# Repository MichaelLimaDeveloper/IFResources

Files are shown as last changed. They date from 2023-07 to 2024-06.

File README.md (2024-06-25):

# IFResources
Controle e Monitoramento de Temperatura e Recursos Hídricos.

## Objetivo
Este repositório foi criado para a publicação dos códigos, documentos e outros arquivos utilizados para a apresentação na disciplina de Projeto Final lecionada por Prof. Dr. Alexandre Domingues Gonçalvez e para a obtenção do grau de Técnico em Informática.

## Resumo
Os arquivos aqui publicados e os temas propostos no documento falam sobre o desenvolvimento de um Web-Site que faz conexão com um micro-controlador do modelo LORA-32 por meio de uma instância Docker hospedada no serviço AWS. Nesse Web-Site são dadas informações como a temperatura e umidade do ambiente dos sensores, a porcentagem do volume de água em um recipiente cujo foi instalado o sensor LC1BD04 e também possibilita o envio de comandos para o infravermelho instalado no dispositivo.

## Créditos
[Gabriel Sales Rodrigues](https://github.com/gaabpng) [Michael Monteiro de Lima](https://github.com/MichaelLimaDeveloper) [Luiz Felipe Silva Oliveira](https://github.com/luizsoliveira)

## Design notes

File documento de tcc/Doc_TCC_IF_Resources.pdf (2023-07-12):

Instituto Federal de Educação, Ciência e

Tecnologia do Rio de Janeiro

### Campus Niterói

Técnico em Informática Integrado ao Ensino

Médio

Gabriel Sales Rodrigues

Michael Monteiro de Lima

Miryam Estábila Nogueira de Souza

# IF Resources:

# Controle e Monitoramento

# de Temperatura e Recursos

# Hídricos

Niterói

2023.1

Gabriel Sales Rodrigues

Michael Monteiro de Lima

Miryam Estábila Nogueira de Souza

## IF RESOURCES:

## CONTROLE E MONITORAMENTO DE TEMPERATURA E RECURSOS HÍDRICOS

Trabalho de Conclusão de Curso submetido ao corpo docente do Instituto Federal de Educação, Ciência e Tecnologia do Rio de Janeiro como requisito parcial para a obtenção do grau de Técnico em Informática.

Orientador: Prof. DSc. Luiz Felipe da Silva Oliveira

Coorientador: Prof. DSc. Alexandre Domingues Gonçalves

Niterói
2023.1

Gabriel Sales Rodrigues

Michael Monteiro de Lima

Miryam Estábila Nogueira de Souza

## IF RESOURCES: CONTROLE E MONITORAMENTO DE TEMPERATURA E RECURSOS HÍDRICOS

Trabalho de Conclusão de Curso submetido ao corpo docente do Instituto Federal de Educação, Ciência e Tecnologia do Rio de Janeiro como requisito parcial para a obtenção do grau de Técnico em Informática.

BANCA EXAMINADORA

Prof. DSc. Luiz Felipe da Silva Oliveira Orientador/IFRJ

Prof. DSc. Alexandre Domingues Gonçalves
Co-Orientador/IFRJ

Dedicamos este trabalho primeiramente a Deus, que nos concedeu a força e a sabedoria necessárias para vencer todos os obstáculos e chegar até aqui. Dedicamos também aos nossos amigos, pelos momentos de descontração que ajudaram a aliviar o estresse e a tensão durante essa caminhada acadêmica. Dedicamos esse trabalho também um ao outro, por não nos abandonarmos durante os 6 longos períodos letivos cursados.

# AGRADECIMENTOS

Ao Instituto Federal de Educação, Ciência e Tecnologia do Rio de Janeiro - Campus Niterói pela oportunidade de adquirir conhecimento por meio de atividades acadêmicas que proporcionam conhecimento prático. Aos docentes Alexandre Domingues Gonçalves, Luiz Felipe Silva Oliveira, Marcelo Japiassu Ramos, Samuel Max Gabbay e Vitor Gabriel de Souza Alencar por nos orientar não só no ponto de vista técnico do projeto, mas também no apoio e ensinamentos passados. Aos nossos amigos Jessyca Nalin Meireles, João Pedro Silverio Gama, Luiz Gabriel Pinheiro, Pedro Henrique Biega Lopes Bandeira, Roger Franclin Queiroz do Nascimento, Samuel Asaph Lima Dias e Tainá Petrucio Fonseca por nos ajudarem, por nos apoiarem e por sempre estarem com a gente quando a gente mais precisou.

# RESUMO

O trabalho de conclusão de curso: “IF Resources: controle e monitoramento de temperatura e recursos hídricos”, busca tornar prática a fiscalização da temperatura das salas e laboratórios do campus, além dos níveis de água das caixas. O projeto visa o aprimoramento e inserção da eletrônica, tecnologias IoT e a Pesquisa e Extensão no dia a dia o IFRJ – Campus Niterói. O público-alvo do projeto são os alunos, professores e equipe de manutenção do campus, com o objetivo de promover o bem-estar de todos. Além disso, o projeto visa alertar os usuários sobre a temperatura antes mesmo de entrarem nas salas, evitando assim problemas de saúde causados por choques térmicos, por exemplo. Também visa alerta o nível d’água do campus, enviantando assim desperdício ou escassez de água. A importância desse projeto reside na facilidade de controle da temperatura dos aparelhos de ar-condicionado, no monitoramento do nível d’água e na supervisão da temperatura e umidade das salas. A ideia é prevenir problemas de saúde decorrentes de dias quentes, uso inadequado dos aparelhos e escassez de água. Além disso, o projeto contribui para evitar o desperdício de energia no campus, o desgaste dos equipamentos e a falta de um recurso essencial como a água.

Palavras-chave: Eletrônica; IoT; Lora 32; Prototipação.

# ABSTRACT

This document presents the project: “IF Resources: control and monitoring of temperature and water resources”, seeks to make it practical to monitor the temperature of the rooms and laboratories on the campus, in addition to the water levels in the tanks. The project aims at the improvement and insertion of electronics, IoT technologies and Research and Extension in the daily life of the IFRJ - Campus Niterói. The project’s target audience is students, teachers and the campus maintenance team, with the aim of promoting the wellbeing of all. In addition, the project aims to alert users about the temperature even before entering the rooms, thus avoiding health problems caused by thermal shocks, for example. It also aims to alert the water level of the campus, thus sending waste or shortage of water. The importance of this project lies in the ease of controlling the temperature of the air conditioners, monitoring the water level and supervising the temperature and humidity in the rooms. The idea is to prevent health problems arising from hot days, inappropriate use of devices and water shortages. In addition, the project helps to avoid wasting energy on the campus, equipment wear and tear and the lack of an essential resource such as water.

Keywords: electronics; Lora 32; IoT and prototyping.

# LISTA DE FIGURAS

1 | Interface do Wokwi | 16
2 | Bibliotecas Wokwi | 17
3 | Interface do Wokwi e do MQTT Dashboard | 18
4 | Fotos do Primeiro Prototipo Físico | 19
5 | Fotos do Segundo Prototipo Físico | 20
6 | Fotos do Terceiro Prototipo Físico | 20
7 | Fotos do Quarto Prototipo Físico | 21
8 | Desenho do Circuito | 22
9 | Diagrama do Circuito | 23
10 | Esquemático do Circuito | 23
11 | Imagem da primeira case modelada em 3D do projeto | 24
12 | Imagem da case atual do projeto modelada em 3D | 24
13 | Imagem da PCB que substituiria a Protoboard | 25
14 | Imagem sobre o protocolo MQTT e seu padrão Publish-Subscribe . . . 26
15 | Trecho de Código onde está definido parâmetros do protocolo MQTT . 27
16 | Trecho de Código onde está definido objetos, strings e variáveis | 27
17 | Imagem onde mostra a biblioteca e o exemplo que foi retirado o funcio-
| namento do SendRaw | 28
18 | Imagem da tela inicial do site | 29
19 | Imagem da pagina do formulário de feedback | 30
20 | Imagem da pagina que informa o nível da caixa d’água | 30
21 | Imagem da pagina que informa a temperatura do ambiente | 31
22 | Imagem da pagina que informa a umidade do ambiente | 31
23 | Imagem da pagina de controle do ar-condicionado | 31
24 | Imagem do painel da instância EC2 que está rodando na AWS | 32
25 | Imagem do painel de configuração da imagem EMQX que está rodando
| na AWS | 32
26 | Imagem do painel de configuração do site que está hospedado na hostinger 33
27 | Imagem da parte interna do equipamento | 33
28 | Imagem da parte superior do equipamento | 34
29 | Imagem da conexão do sensor de tempereatura e umidade DHT22 no
| Lora 32 | 34
30 | Imagem da conexão do transmissor infra-vermelho HX-53 no Lora 32 . 35
31 | Representação do funcionamento do nível de água | 36
32 | Imagem da conexão do sensor de nível de água Diy 4 no Lora 32 . . . . 36
33 | Imagem do Equipamento Finalizado | 37

# SUMÁRIO

10

# 1 INTRODUÇÃO

O IFRJ campus Niterói possui vários laboratórios com equipamentos que têm que trabalhar e que precisam ser operados em condições climáticas de acordo com a especificação técnica. relatos da equipe técnica apontam que constantemente alguns equipamentos apresentam defeitos por não estarem operando em uma temperatura adequada. Além disso, também há um outro problema que afeta o campus que é a falta d’água. Vários alunos e funcionários do mesmo reclamaram sobre esse problema.

Visando solucionar esse problema, alguns alunos do semestre 2022.2 começaram a idealizar uma solução para tentar minimizar o problema reportado acima. Portanto, as seguintes propostas de projeto foram definidas: A construção de uma central de monitoramento e controle do ar-condicionado, e ao mesmo também um nível de água para uma caixa d’água ou reservatório.

Portanto, o equipamento desenvolvido é um termostato e um nível d’água, que tem como nome "IF Resources". Nessa central de monitoramento e controle é possível: monitorar o nível d’água, monitorar a temperatura ambiente de uma sala e o controlar o ar-condicionado. Isso é feito utilizando protocolo MQTT, já que permite envio e recebimento de informações.

Usaremos componentes como o Heltec Lora 32, um microcontrolador voltado para IoT, juntamente de um Sensor de Temperatura e Umidade e um transmissor infravermelho. Tudo isso conectado em uma PCB feita exclusivamente para o projeto e por fim, acoplado dentro de uma case impresso utilizando uma impressora 3D.

O público alvo do projeto é os discentes, docentes e equipe de manutenção para ajudar a manter o bem estar de todos no campus. Também há a questão de que se algum ar-condicionado estiver com problema, o indivíduo usuário do site saberá antes mesmo de entrar na sala, em caso de até mesmo de evitar problemas de saúde como um eventual choque térmico por exemplo.

A importância desse projeto é para facilitar o controle da temperatura dos ar-condicionado, facilitar e proporcionar monitoramento de nível d’água e facilitar o monitoramento da temperatura e umidade dos ambientes de sala. A ideia é evitar que os alunos, docentes e servidores tenham problemas de saúde por conta de dias quentes e o mau uso do aparelho e/ou a falta d’água. Evitar o desperdício de energia do campus, desgastes do aparelho e falta de um recurso essencial como a água.

Capítulo 1. Introdução | 11

## 1.1 Justificativa

A Necessidade de monitorar e de controlar a temperatura das salas de aula em dias de calor para que o ar condicionado seja ligado ou não, evitando o desperdício de energia, desgaste do aparelho e problemas de saúde de todos do campus devido ao calor ou ao mau uso. Também com o objetivo de controlar a temperatura das salas de aula e manter os alunos do campus em uma temperatura ideal e também, economizar energia da escola, equilibrando entre o conforto dos que estão na aula e a economia de energia da escola. Essa temperatura definida pela escola é de em média 22 a 23 graus. Também há a necessidade de monitorar o nível d’água do campus, já que frequentemente os alunos sofrem com a falta d’água. Então, um nível d’água via web traz uma praticidade no monitoramento que possam saber a hora certa de abastecer ou economizar a água do campus.

## 1.2 Objetivo

O objetivo do projeto é oferecer um equipamento que é um medidor de temperatura de ambiente, um controle de ar-condicionado e um nível d’água reunidos em sistema, ou seja, uma central de monitoramento e controle.

1.2.1 Objetivo Geral

O objetivo geral do projeto é suprir a necessidade de monitorar e controlar a temperatura das salas de aulas e também monitorar o nível d’água da instituição com o objetivo manter o bem-estar de todos, bem como prover meios de economizar água e energia da escola.

1.2.2 Objetivos Específicos

Os objetivos específicos que auxiliaram no atendimento do objetivo geral deste projeto são os seguintes:

- Permitir a leitura da temperatura de um certo ambiente usando o Sensor de tempe-

ratura e umidade DHT22;

- Permitir o controle do ar condicionado através do envio de informações para executar

ações de aumento, acionamento e diminuição usando um transmissor infravermelho HX-53;

- Permitir a leitura do nível d’água de uma caixa d’água ou reservatório de água

usando o sensor eletrônico de nível d’água diy 4;

- Produzir um site que seja interface de controle e monitoramento do usuário;

Capítulo 1. Introdução | 12
- O Projeto seja fácil e prático de ser utilizado para o usuário e de simples manutenção,

ou que seja simples de fazer melhorias, ou seja, upgrades no projeto;

- O Projeto seja Open Source, com todas as fontes e todo o projeto esteja postado no

github dos criadores e que sirva de material para o aprendizado de outras pessoas;

- O Projeto sirva a instituição solucionando ou minimizando a sua dor, ou seja,

atendendo as necessidades com a nossa solução proposta com a solução proposta.

## 1.3 Metodologia

A metodologia é um conjunto de passos e estratégias adotadas que facilitam o andamento e o desenvolvimento do projeto, tendo isso em mente, os pontos seguidos para a elaboração do projeto foram:

1. Ideação: A necessidade de criar um equipamento que monitora o nível de água e a temperatura de um ambiente; e que também controla um ar-condicionado via internet através de um site utilizando tecnologias IoT. Para isso utilizamos da uma técnica chamada brainstorming para organizarmos as ideias e selecionar as ideias a serem implementadas;
2. Planejamento: Para o acompanhamento do projeto, a definição das suas funcionalidades e suas tarefas foi feita na plataforma Trello (ATLASSIAN, 2017);
3. Definição das funcionalidades: As funcionalidades aplicadas são o monitoramento de água do campus, o monitoramento da temperatura e umidade do campus e o controle do ar-condicionado. No caso do controle, suas funções são: Ligar, Desligar, Aumentar a Temperatura, Diminuir a temperatura;
4. Prototipação: O protótipo trata-se de um conjunto dos componentes que são: Sensor de Temperatura e Umidade DHT22, Transmissor infravermelho HX-53, Sensor Eletrônico de Nível d’água Diy 4 Níveis e um microcontrolador Heltec Lora 32. A junção de todos esses componentes resulta em uma central de controle e monitoramento para o campus, a ideia é juntar todos esses componentes em uma case impressa em 3D;
5. Configuração dos Ambientes de Desenvolvimento: Os ambientes de trabalho do projeto são as tecnologias utilizadas para o desenvolvimento do projeto, e as que foram escolhidas pelos criadores são: Arduino IDE (ARDUINO, 2005), AWS (AMA-ZON WEB SERVICES INC, 2006), Docker (DOCKER INC, 2013), EasyEDA (EASYEDA INC, 2013), Figma (FIELD, 2016), Fritzing (FRITZING INC, 2014), Github (GITHUB INC, 2008), Hostinger (HOSTINGER INTERNATIONAL LTD

Capítulo 1. Introdução | 13

, 2004), TinkerCad (AUTODESK, 2011), UltiMaker Cura (ULTIMAKER, 2011), Visual Studio Code (MICROSOFT, 2015) e o Wokwi (CODEMAGIC LTD, 2019);

6. Implementação: Aplicar tudo que foi desenvolvido ao longo do projeto, aplicar todas as tecnologias utilizadas e transformar o protótipo em produto final, ou seja, o equipamento proposto pelo time de desenvolvedores do projeto em sua versão final para a defesa da ideia e do projeto. Ao final, aplicar e implementar o equipamento no campus para solucionar a dor;
7. Defesa: Para a defesa de TCC, esse projeto foi necessário a confecção do documento de TCC, a confecção de uma apresentação e a finalização do equipamento final para apresentação e demonstração de seu funcionamento e suas funcionalidades.

14

# 2 DESENVOLVIMENTO DO PROJETO

O desenvolvimento do projeto trata-se da aplicação de toda a metodologia dita capítulo anterior visando atender os objetivos do projeto desenvolvendo o equipamento proposto e justificando ele através da sua utilidade para solucionar a dor e as necessidades do campus na versão final do projeto. O desenvolvimento do projeto também busca mostrar todo o caminho, todos os passos e tudo que foi feito no projeto, desde sua descrição até os protótipos desenvolvidos ao longo tempo dentro do mesmo.

## 2.1 Descrição Geral da Proposta

A proposta do termostato é ser uma central de monitoramento e controle do ar-condicionado feita utilizando componentes como o Heltec Lora 32 que é uma placa de desenvolvimento que utiliza o chip Xtensa® Dual-Core 32-bit LX6, o mesmo do ESP32-

S3FN8, porém com uma frequência maior de 240MHz. A placa também tem embutido o display OLED SSD1306 monocromático. Utilizamos também os componentes eletrônicos como: O Sensor de Temperatura DHT22, O Transmissor Infravermelho HX-53 e a placa de nível d’água Diy 4. Para o desenvolvimento do programa implementado no hardware foi utilizado a linguagem de programação C/C++ e o framework Arduino IDE, utilizando várias bibliotecas de suporte aos componentes, conexão à internet e protocolo MQTT.

Já o site foi desenvolvido usando tecnologias como HTML, CSS, JavaScript e Docker. No caso o HTML e CSS para a interface de usuário e o JavaScript e Docker para a comunicação com o Broker que se comunica com o hardware que está enviando informações dos sensores para o broker ou executa os comandos vindo do broker através de mensagens MQTT. Também usamos plataformas como a hostinger para a hospedagem do site e a aws para hospedar o container em uma instância criada no Amazon EC2.

O equipamento foi montado em uma protoboard de 400 pontos e acoplado dentro de uma case modelada em 3D no TinkerCad e impressa em 3D no campus com o material ABS e também utilizando o software UltiMaker Cura para efetuar o fatiamento 3D.

Os códigos do projeto são Open Source e estão disponíveis no github dos criadores do projeto para aqueles do campus que quiserem fazer manutenção ou quiserem melhorar o projeto fazendo upgrades.

Capítulo 2. Desenvolvimento Do Projeto | 15

## 2.2 Lista de Requisitos

REQ1 - Deverá medir a temperatura e umidade do ambiente através de um Sensor de temperatura e umidade DHT22 conectado ao Lora 32 através de jumps em uma protoboard.

REQ2 - Deverá controlar o ar-condicionado emulando um controle de ar-condicionado modelo Elgin Eco através de um transmissor infravermelho HX-53 conectado ao Lora 32 através de jumps e uma protoboard.

REQ3 - Deverá monitorar o nível d’água de caixa d’água ou reservatório de água do campus através do sensor eletrônico de nível d’água diy 4.

REQ4 - Deverá ter um site de controle e monitoramento online que tenha botões para acessar as páginas que informam o nível d’água, temperatura e umidade; e uma página com botões para cada controle do ar-condicionado: Ligar, desligar, aumentar temperatura e diminuir temperatura.

REQ5 - Deverá usar o protocolo MQTT e o protocolo WebSocket para a comunicação entre o equipamento e o site.

REQ6 - Deverá usar um container no Docker e uma instância EC2 no AWS para o suporte aos protocolos e ao broker utilizados no projeto.

REQ7 - Deverá ter uma case impressa em 3D para comportar as peças e montar o equipamento proposto pelo projeto.

Capítulo 2. Desenvolvimento Do Projeto | 16

## 2.3 Processo de Prototipagem

O processo de prototipagem do hardware está dividido em algumas partes como: Primeiros protótipos do projeto que foi feito no Wokwi um software de simulação de projetos eletrônicos online com suporte a ESP32, funções IoT do mesmo e alguns componentes necessários do projeto. Primeiros Protótipos Físicos, onde foi usado o software Arduino IDE para software programado em C/C++ e utilizando algumas bibliotecas que foi carregado no Heltec Lora 32, além das práticas de solda e montagem dos componentes físicos e também da criatividade dos desenvolvedores do projeto. No circuito eletrônico foi usado o software Fritzing para o desenho e montagem do circuito eletrônico do projeto. No desenho 3D foi utilizado o TinkerCad para a modelagem 3D da case do equipamento e o UltiMaker Cura para o fatiamento para impressão 3D da case. Por fim foi utilizado o EasyEDA para o desenho da placa de circuito impresso do projeto.

2.3.1 Primeiros Protótipos no Simulador

Primeiro Protótipo: Os testes foram feitos inicialmente pelo simulador Wokwi, como mostrado na imagem abaixo, esse teste abaixo é somente para a verificação e entendimento do funcionamento de uma parte do projeto. No caso um sensor de temperatura e umidade DHT22 mostrando a temperatura coletada do “ambiente”. Porém isso o que é demonstrado abaixo foi um primeiro “esboço” do projeto.

- Interface do Wokwi com o protótipo:

Figura 1 – Interface do Wokwi

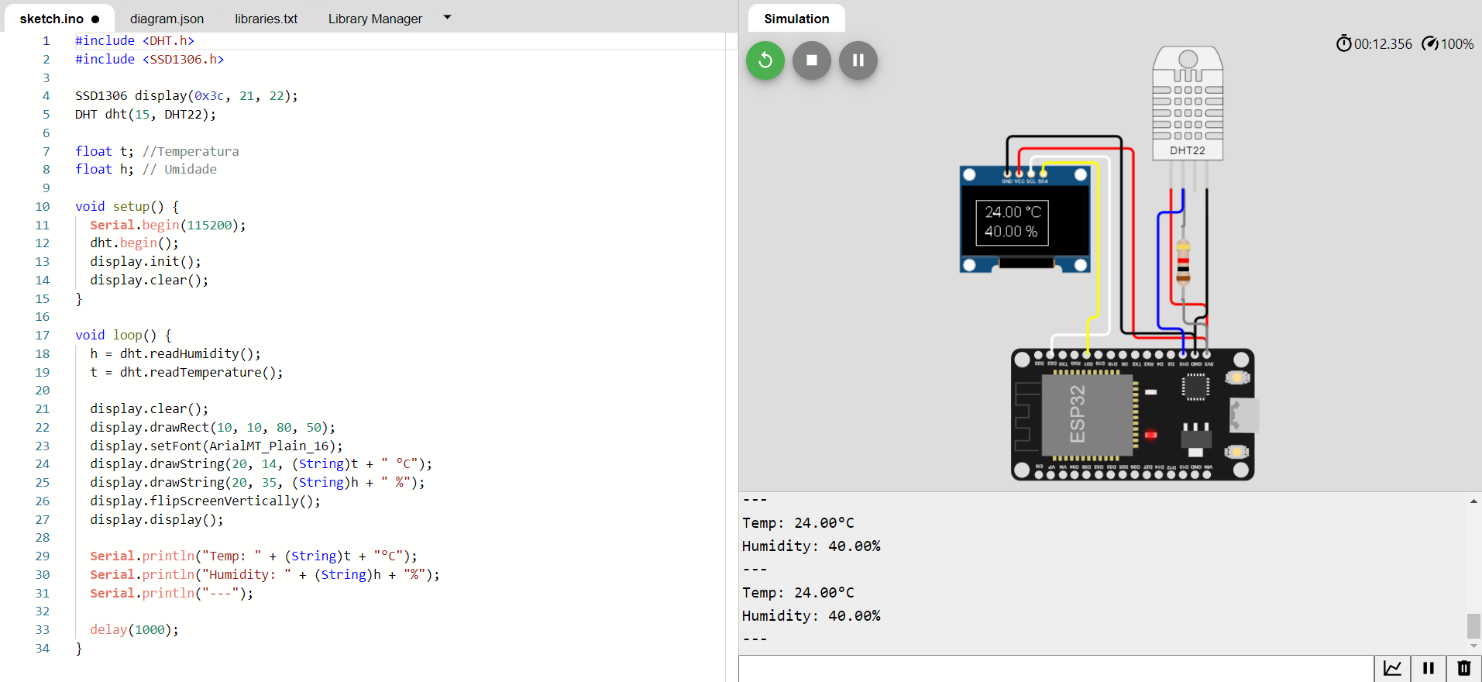
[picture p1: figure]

Capítulo 2. Desenvolvimento Do Projeto | 17
- Bibliotecas utilizadas:

Figura 2 – Bibliotecas Wokwi

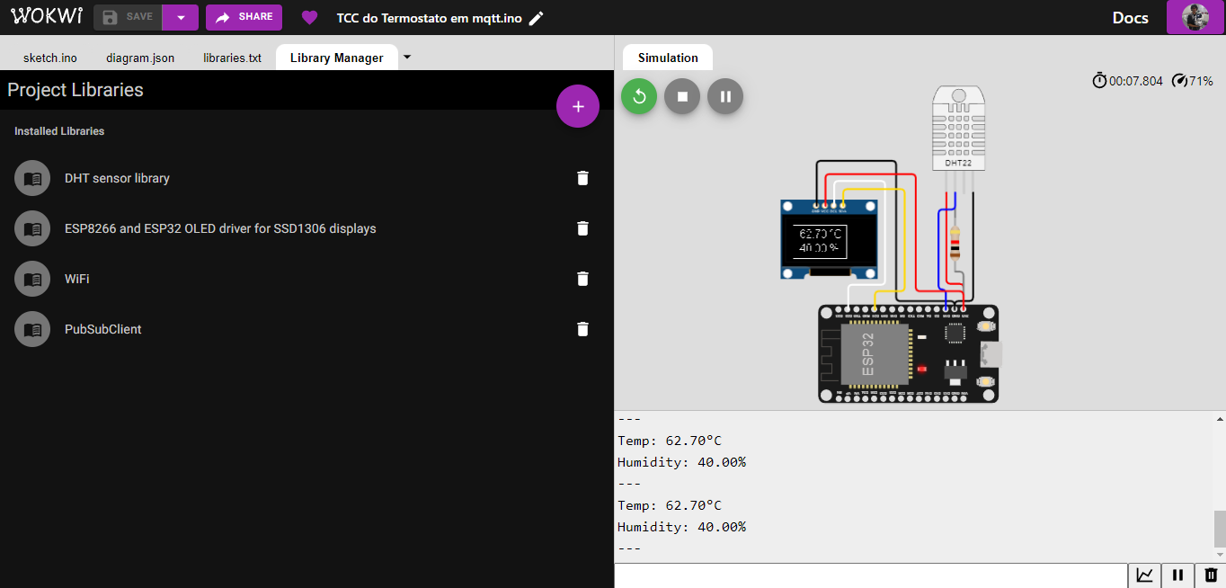
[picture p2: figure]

Capítulo 2. Desenvolvimento Do Projeto | 18

Segundo Protótipo: Nesse protótipo, usando como base o protótipo anterior, foi desenvolvido o código que se conecta a uma rede Wi-Fi com internet e que faz o envio das informações captadas pelo sensor de temperatura e umidade DHT22 para um broker MQTT. No código é mostrado que o envio das informações é feito através de um tópico MQTT e usando o aplicativo MQTT dashboard, criamos uma interface onde podemos colocar o tópico em uma caixa de exibição do aplicativo para justamente exibir as informações enviadas. Na prática o “hardware” não mudou nada, apenas o código que estará disponível dos criadores.

- Interface do Wokwi com o segundo protótipo e a interface de controle e monitoramento

no MQTT dashboard:

Figura 3 – Interface do Wokwi e do MQTT Dashboard

A configuração do MQTT Dashboard consiste em criar uma aba para onde ficará a sua interface e durante a criação dessa aba você deve colocar o endereço e a porta do broker MQTT que está sendo utilizado. No caso deste protótipo o endereço “broker.hivemq.com” com a porta “1883”. Depois disso deve-se criar botões que serão as caixas de exibição para cada tópico MQTT definido no código, nesse caso, um para o Tempo, um para a Temperatura e um para Umidade. Esses botões de ligar e desligar, aumentar a temperatura e diminuir a temperatura são funcionais para o protótipo físico.

Capítulo 2. Desenvolvimento Do Projeto | 19

2.3.2 Primeiros Protótipos Físicos

Primeiro Protótipo: O primeiro protótipo físico foi montado inteiramente em uma protoboard de 830 pontos com jumps e não tinha uma case e tela ainda não exibia as informações de temperatura. Ao mesmo tempo, de forma separada tinha um protótipo específico para o nível d’água, ou seja, não era tudo junto no início do projeto e de novo, a tela ainda não exibia nada.

- Primeiro protótipo físico ainda usando apenas a protoboard

Figura 4 – Fotos do Primeiro Prototipo Físico

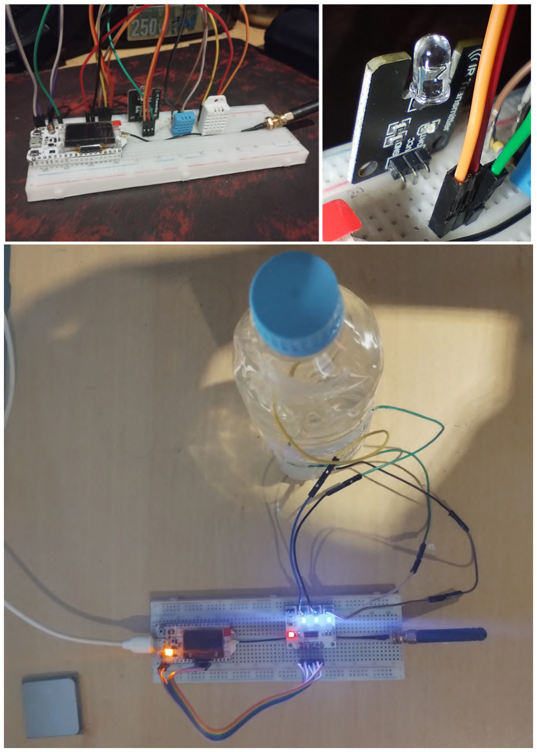
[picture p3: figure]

Capítulo 2. Desenvolvimento Do Projeto | 20

Segundo Protótipo: Para o segundo protótipo foi feito uma case feita de isopor com uma tampa que tem um buraco para a tela OLED com uma plástico transparente para proteger a tela, nesse protótipo ainda era usado a protoboard de 830 pontos. Como o nível d’agua ainda estava separado, ainda não havia uma case para ele.

- Segundo protótipo físico com a case de isopor

Figura 5 – Fotos do Segundo Prototipo Físico

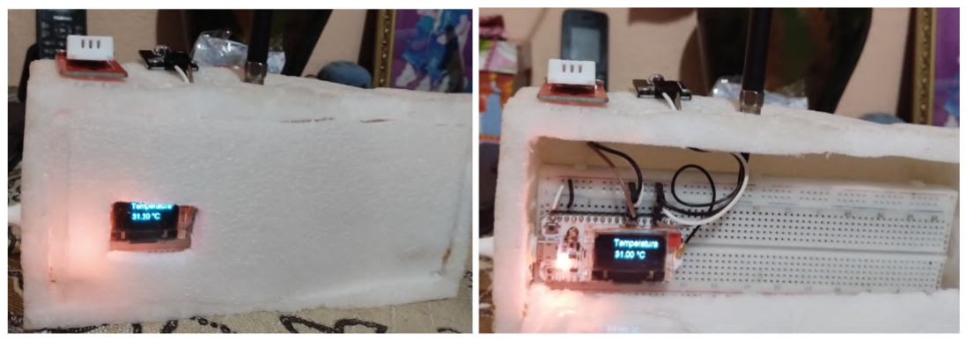
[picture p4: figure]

Terceiro Protótipo: Para o terceiro protótipo foram feitas as seguintes adaptações: primeiro que a case de isopor foi cortada ao meio já que houve a troca da protoboard de 830 pontos por uma protoboard de 400 pontos, assim diminuindo o tamanho do protótipo.

- Terceiro protótipo físico com a nova protoboard e a case de isopor reduzida

Figura 6 – Fotos do Terceiro Prototipo Físico

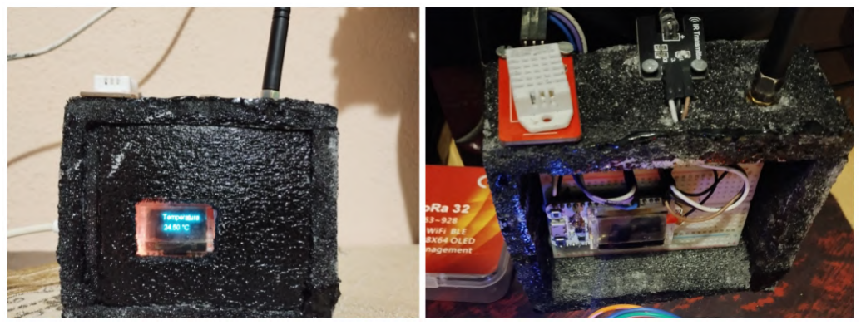
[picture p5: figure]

Quarto Protótipo: Para o quarto protótipo foi impresso em 3D uma case nova utilizando as medidas dos componentes e principalmente da protoboard como base para modelar a case. O equipamento foi impresso em material ABS, porém não ficou com todas as medidas corretas e também faltou a cavidade para a tela do Lora 32 na tampa e faltou a cavidade para a conexão USB do Lora 32. Basicamente era uma case fechada.

- Quarto protótipo físico com a nova case impressa em 3D

Capítulo 2. Desenvolvimento Do Projeto | 21

Figura 7 – Fotos do Quarto Prototipo Físico

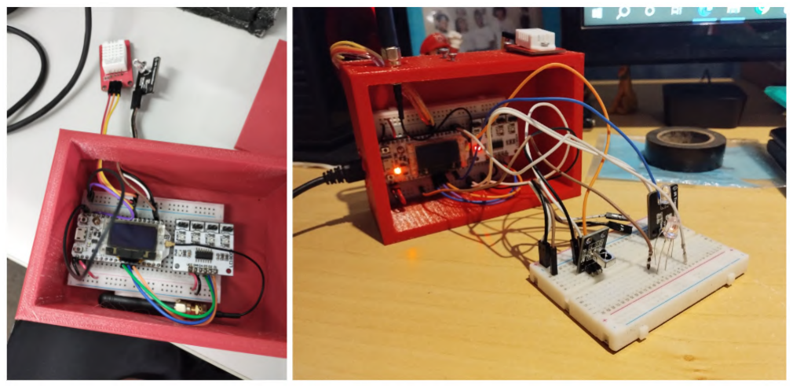
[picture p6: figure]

Capítulo 2. Desenvolvimento Do Projeto | 22

2.3.3 Circuito Eletrônico

O circuito eletrônico foi desenhado no software Fritzing. Nele há o desenho do circuito, o diagrama e o esquemático. Explicando as conexões, temos um microcontrolador Lora 32 conectado à uma protoboard, através de jumps, o Sensor de Temperatura e Umidade DHT22 (Que está ligado na porta 25 do Lora 32), o Sensor Eletrônico de nível d’água diy 4 (Que está ligado nas portas 36, 37, 38 e 39 do Lora 32) e o Transmissor infravermelho HX-53 (Que está ligado na porta 13 do Lora 32) também estão conectados na protoboard nas respectivas trilhas que estão conectados os pinos que estão definidos na programação do Lora 32 para seu respectivo funcionamento. Infelizmente nesse circuito não terá a representação do Sensor Eletrônico de nível d’água diy 4 porque o mesmo não se encontra presente no software Fritzing.

- Imagens referentes ao circuito eletrônico

Figura 8 – Desenho do Circuito

Capítulo 2. Desenvolvimento Do Projeto | 23

Figura 9 – Diagrama do Circuito

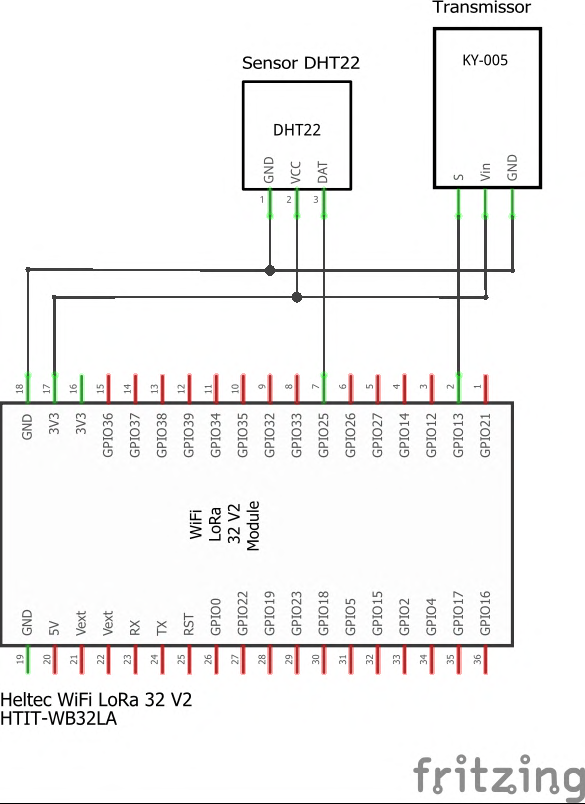
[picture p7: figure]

Figura 10 – Esquemático do Circuito

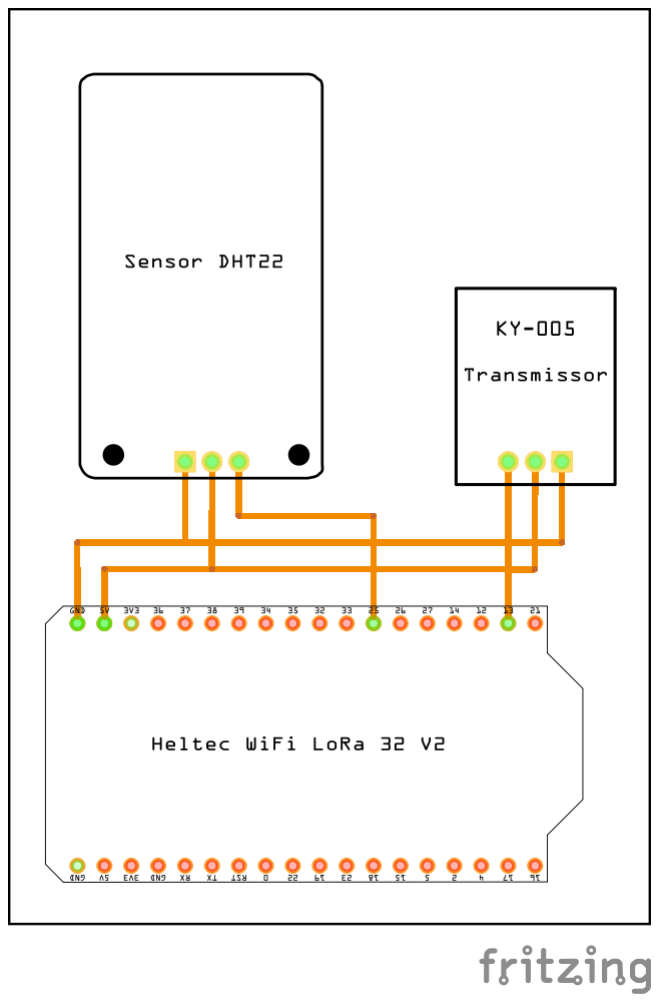
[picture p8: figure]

Capítulo 2. Desenvolvimento Do Projeto | 24

2.3.4 Desenho 3D e Desenho da PCB

A case foi desenvolvida por Gabriel Sales e Michael Lima para comportar todos os componentes necessários. Que são a protoboard de 400 pontos, o Lora 32, o Sensor de Temperatura e umidade DHT22, e o Transmissor Infravermelho HX-53. Ele foi desenvolvido em um software chamado Tinkercad da Autodesk em uma parte específica do software que é voltada para modelagem 3D.

- Primeiro Modelo 3D da case feito anteriormente para comportar a protoboard de

830 pontos

Figura 11 – Imagem da primeira case modelada em 3D do projeto

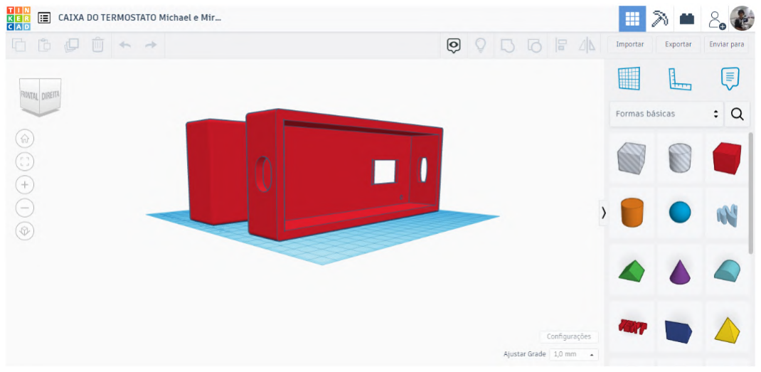
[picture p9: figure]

- Último Modelo 3D feito para comportar a protoboard de 400 pontos com o seus

componentes, assim sendo a versão final e definitiva da case para o equipamento

Figura 12 – Imagem da case atual do projeto modelada em 3D

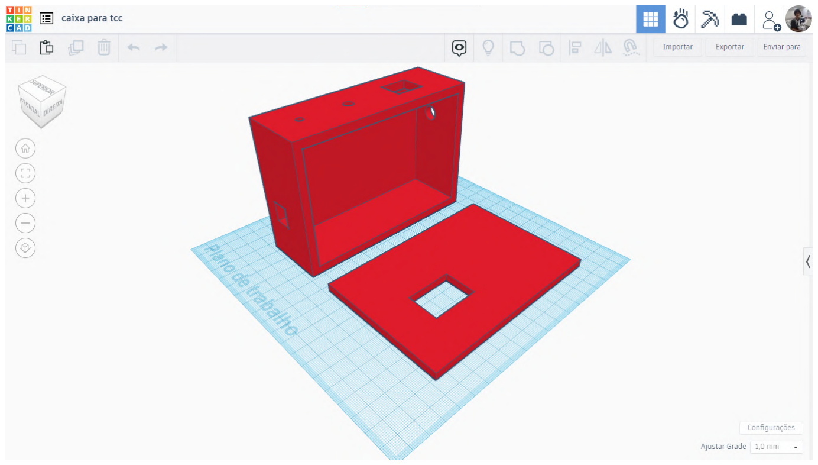
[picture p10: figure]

Capítulo 2. Desenvolvimento Do Projeto | 25

A PCB foi desenvolvida por Gabriel Sales e Michael Lima para comportar todos os componentes necessários em uma placa de circuito impresso sem a necessidade de usar protoboard, ou seja, substituindo a protoboard. A ideia é imprimir essa peça do projeto na prototipadora PCB Voltera V-One que está presente no campus, mas por motivos de tempo do co-orientador, a PCB não pode ser impressa a tempo da data de entrega do TCC e sua defesa. Porém o desenho do circuito impresso foi feito no software chamado EasyEDA.

- Nesse modelo temos o socket para o Lora 32 e as portas para os sensores: DHT22 e

DIY 4; e para o transmissor infravermelho HX-53

Figura 13 – Imagem da PCB que substituiria a Protoboard

26

# 3 IMPLEMENTAÇÃO FINAL

A implementação final é no que diz respeito a parte final do projeto, a conclusão, o que foi feito e como os desenvolvedores do projeto efetuou na prática o projeto.

## 3.1 Passo a Passo

Nessa sessão mostraremos passo-a-passo como foi realizado o projeto.

3.1.1 Passo 1 - Programação do hardware

O Desenvolvimento do software integrado no hardware, que é o código em C/C++ desenvolvido que está carregado no Lora 32. A linguagem de programação a ser utilizada é o C/C++ usando uma IDE (Integrated Development Environment) chamada Arduino IDE como ambiente de desenvolvimento, que dá suporte além dessa linguagem e dá suporte a bibliotecas que estamos utilizando como DHT sensor library, Heltec ESP32 Dev-Boards, WiFi, PubSubClient, IRremote e drivers como USB Silicon Labs CP210x para UART Bridge VCP que dão suporte ao Lora 32 e os todos os componentes que utilizamos como o sensor de temperatura e umidade DHT22 e o transmissor infravermelho HX-53, que transmite os comandos do ar-condicionado.

Esses tópicos podemos chamar de protocolos MQTT, pois, através deles que a informação é enviada ao um broker, que é o chamado publisher. E também que o aplicativo possa receber essa informação que está no broker, que é chamado de subscriber. Também acontece o caminho contrário deste tráfego de informação, que aí no caso o publisher será o aplicativo e o subscriber o Lora 32, geralmente emulando comandos de algum controle e atribuindo a botões no aplicativo.

- As imagens a seguir tirada de uma aula de hardwares programáveis II exemplifica

isso:

Figura 14 – Imagem sobre o protocolo MQTT e seu padrão Publish-Subscribe

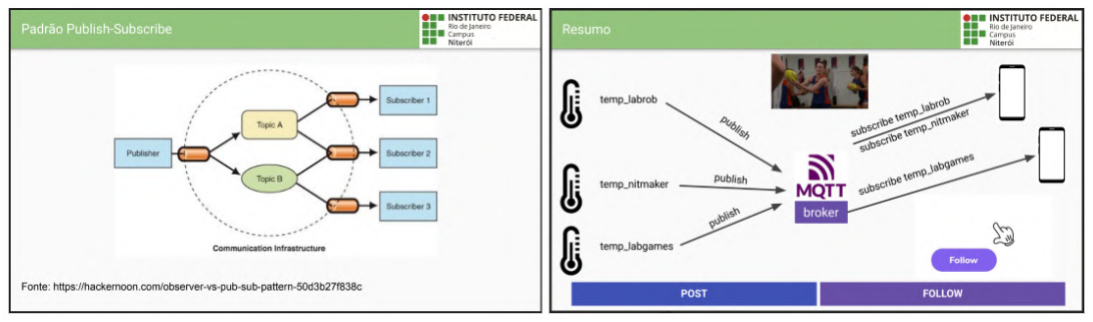
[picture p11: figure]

Capítulo 3. Implementação Final | 27

Com isso em mente, no código foi incluído um arquivo correspondente a configuração da porta do Transmissor Infravermelho e foi incluído as bibliotecas citadas no início do texto. E após isso foram definidos os parâmetros da rede e os parâmetros do protocolo MQTT como ID, Broker, Porta e os Tópicos:

Figura 15 – Trecho de Código onde está definido parâmetros do protocolo MQTT

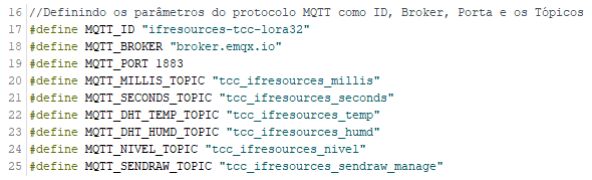
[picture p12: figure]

Após isso foi definido o objeto para a conexão Wi-Fi e criação do cliente MQTT, definido as Strings usadas para o envio das informações, definido a banda de frequência de comunicação sem fio e definido o objeto para o DHT22 e definido variáveis e as funções.

Figura 16 – Trecho de Código onde está definido objetos, strings e variáveis

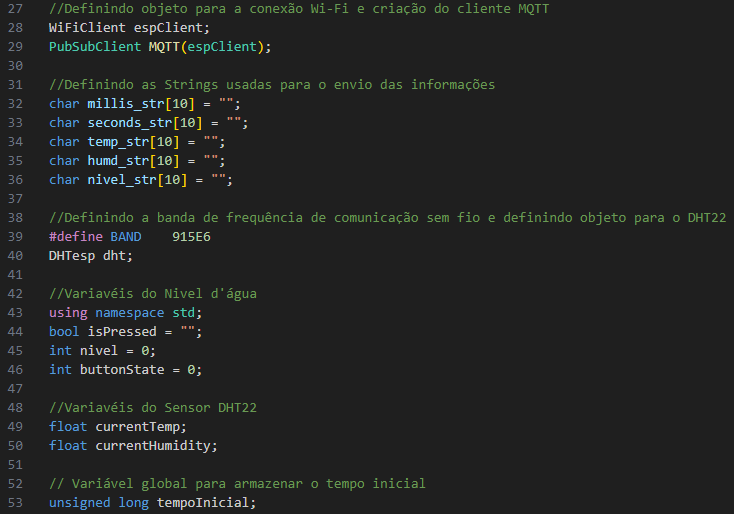
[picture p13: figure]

Depois disso, definidos 8 funções, sendo elas: “void setupWifi()”, “void setupMQTT”, “void getTemp()”, “void getHumidity()”, “void getNivel()”, “void setup(void)”, “void loop(void)” e “void mqtt_ifresources_callback(char* topic, byte* payload, unsigned int length)”.

Explicando cada uma: a “void setupWifi()” é a função que conecta o Lora 32 em algum Wi-Fi, a “void setupMQTT” é a função que conecta o Lora 32 no Broker MQTT,

Capítulo 3. Implementação Final | 28

“void getTemp()” é função da Temperatura, “void getHumidity()” é função da Umidade, “void getNivel()” é função do Nível d’água, “void setup(void)” é a função onde é definido a configuração da primeira tela e a pinagem de alguns componentes, “void loop(void)” é a função onde é definido a configuração da segunda tela que mostra a temperatura e aonde é enviado as informações para o broker e “void mqtt_ifresources_callback(char* topic, byte* payload, unsigned int length)” é a função Callback onde é configurado os comandos do ar-condicionado de ligar, desligar, aumentar e diminuir a temperatura. Na função “void mqtt_ifresources_callback(char* topic, byte* payload, unsigned int length)” usamos como base dois códigos. Um código referência é o que se encontra no github do usuário “luizsoliveira” no repositório “arduinoExamples” lá tem um exemplo de código com comunicação bidirecional MQTT que tem uma função callback muito parecida com a utilizada neste código.

Dentro da função callback falada anteriormente, há uma sequência de condições “if e else if” dentro de cada uma delas, há um bloco condicional com um comando referentes ao sendRaw que é um array dos comandos infravermelhos captados pelos controles do ar-condicionado e isso foi retirado de um exemplo da biblioteca IRremote que o exemplo “SendRawDemo”, então por isso que há um arquivo específico chamado "PinDefinitionsAndMore.h"para definir o pino do transmissor infravermelho HX-53, que no caso é o pino 13, esse arquivo é derivado desse exemplo da biblioteca.

Para a visualização do código completo e compreensão melhor do mesmo, acesse o github dos desenvolvedores do projeto.

Figura 17 – Imagem onde mostra a biblioteca e o exemplo que foi retirado o funcionamento do SendRaw

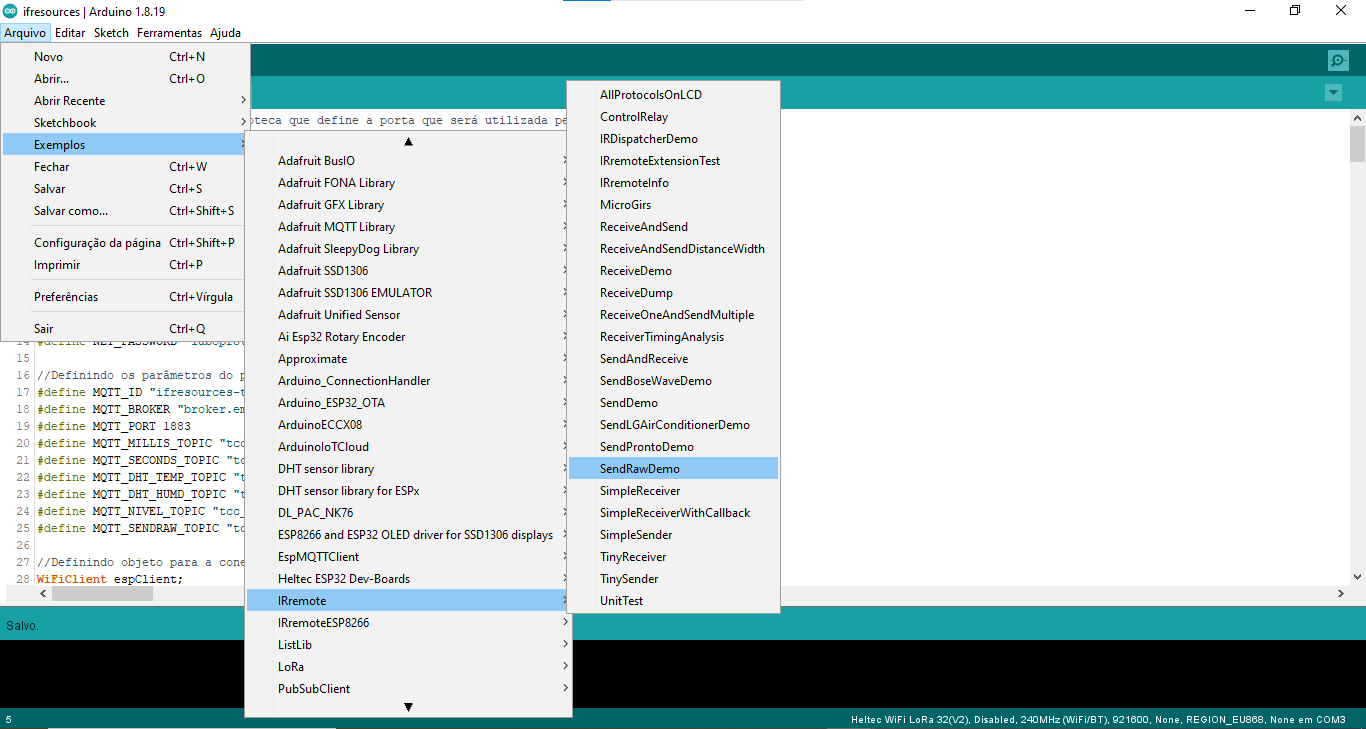
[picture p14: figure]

3.1.2 Passo 2 - Desenvolvimento do Site

O desenvolvimento do site, onde usamos linguagens de marcação e linguagens de programação como HTML, CSS e JavaScript, para isso usamos o Visual Studio Code como

Capítulo 3. Implementação Final | 29

ambiente de desenvolvimento.

Começando pelo Index.html, temos cinco botões levando para diferentes páginas, sendo elas:

Figura 18 – Imagem da tela inicial do site

- Nos mande um feedback! - Envia o usuário para um site externo de formulários,

que envia o feedback do mesmo para o e-mail dos desenvolvedores.

- Veja o nível da Caixa D’água - Envia o usuário para uma web-page que é

subscriber do tópico "tcc_ifresources_nivel".

Capítulo 3. Implementação Final | 30
- Veja a Temperatura - Envia o usuário para uma web-page que é subscriber do

tópico "tcc_ifresources_temp".

- Veja a Umidade - Envia o usuário para uma web-page que é subscriber do tópico

"tcc_ifresources_humd".

- Controle o Ar-condicionado - Envia o usuário para uma web-page que é publisher

do tópico "tcc_ifresources_sendraw_manage".

Figura 19 – Imagem da pagina do formulário de feedback

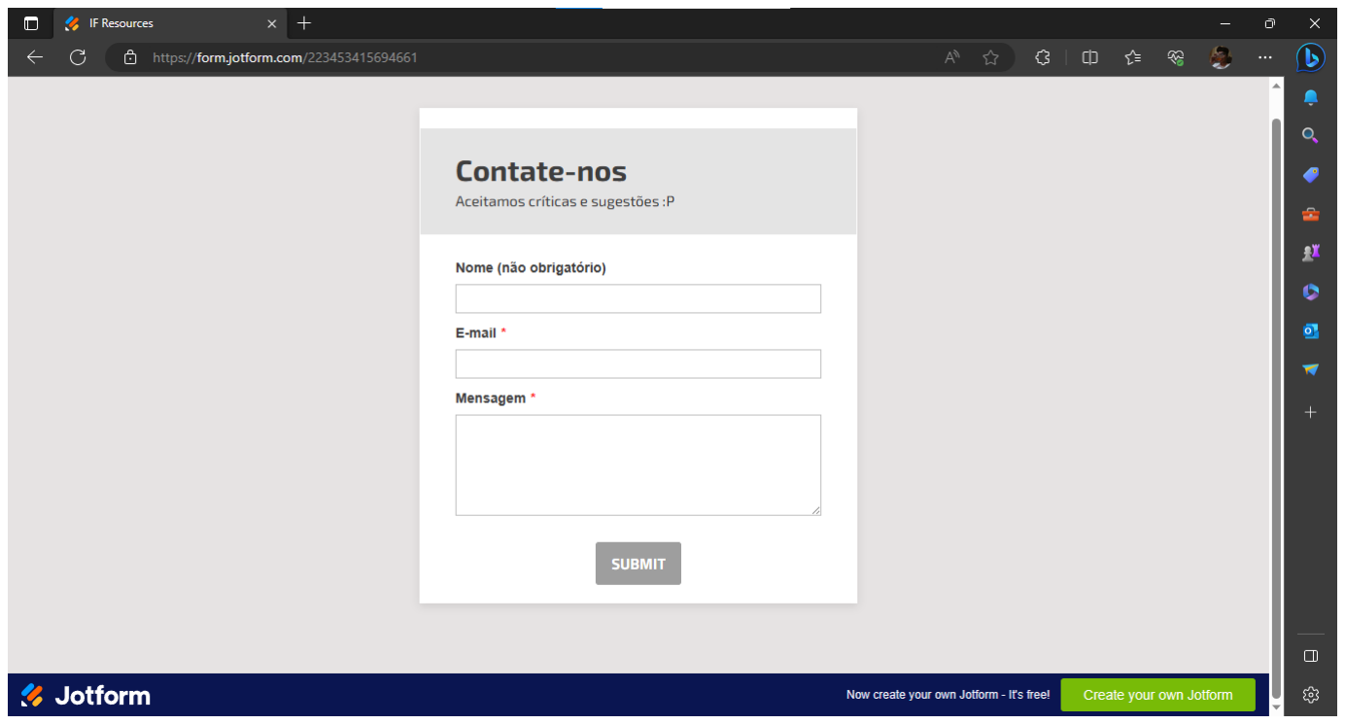
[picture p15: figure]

Figura 20 – Imagem da pagina que informa o nível da caixa d’água

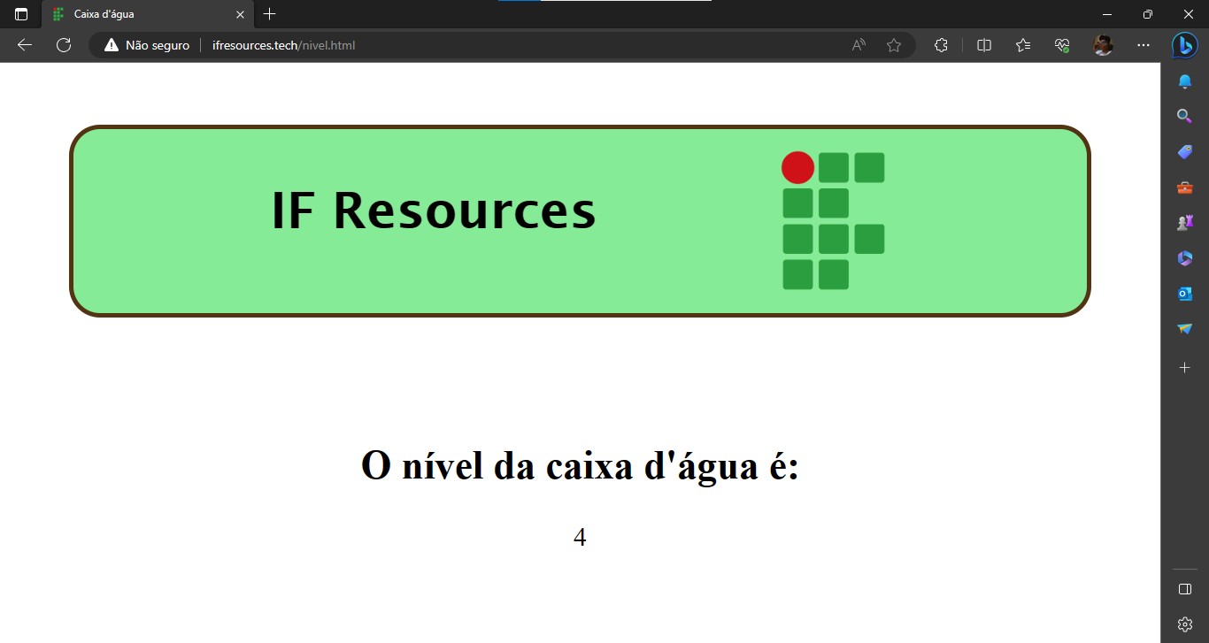
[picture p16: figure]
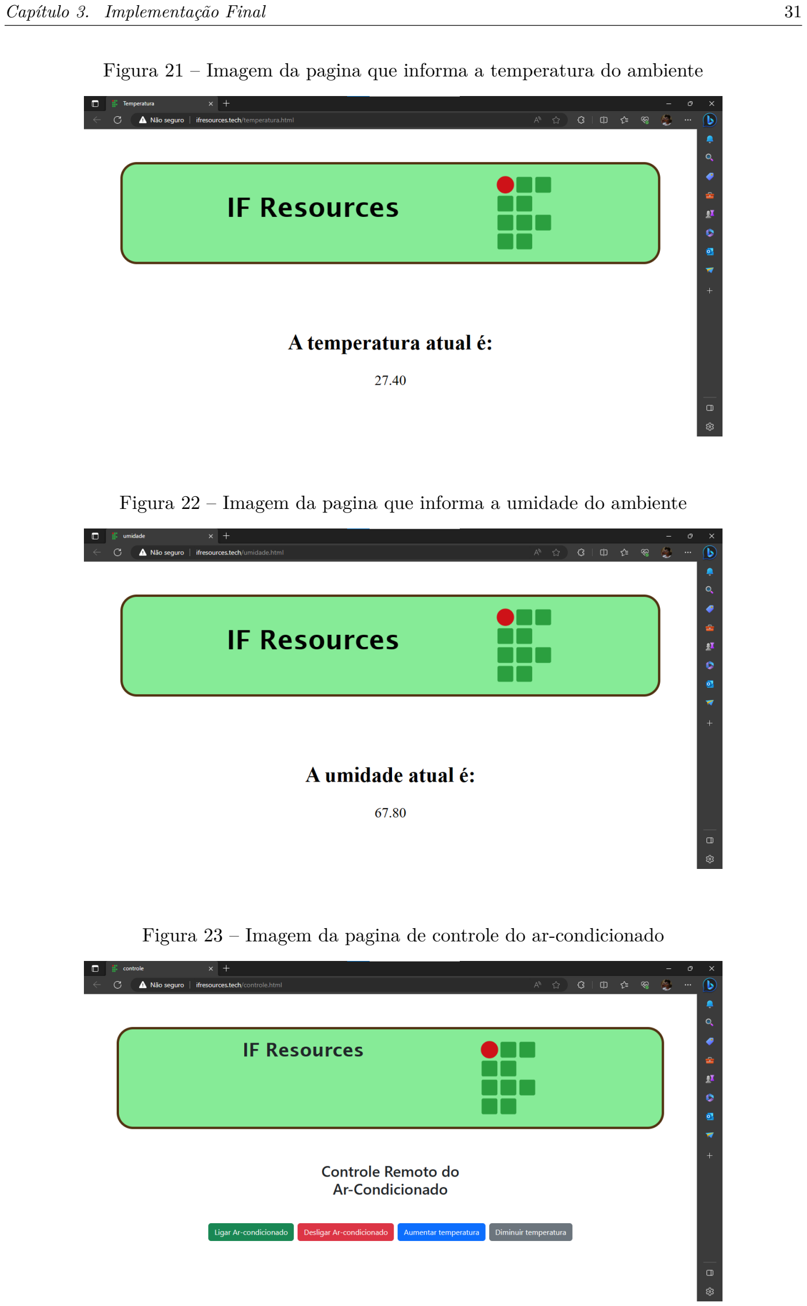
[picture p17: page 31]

Capítulo 3. Implementação Final | 31

Figura 21 – Imagem da pagina que informa a temperatura do ambiente

Figura 22 – Imagem da pagina que informa a umidade do ambiente

Figura 23 – Imagem da pagina de controle do ar-condicionado

Capítulo 3. Implementação Final | 32

Cada página faz seu respectivo papel por meio de um código em JavaScript que o conecta a web-page ao MQTT, atualizando assim a mensagem na tela (podendo ela ser de temperatura, umidade ou nível de água) ou enviando uma mensagem para o tópico. Essa mensagem enviada para o tópico tcc_ifresources_sendraw_manage foi configurada para enviar um comando por meio de infra-vermelho para o ar-condicionado fazer a ação desejada pelo usuário. Essa conexão entre a web-page e o MQTT é feito por meio de um protocolo Web-socket, protocolo esse que necessita de um container no Docker configurado com uma imagem EMQX que faz a comunicação do protocolo WebSocket e do protocolo MQTT. Esse container no Docker está instalado em uma instância EC2 que opera com o sistema operacional ubuntu na AWS. O site está hospedado na hostinger e tem o dominio

Figura 24 – Imagem do painel da instância EC2 que está rodando na AWS

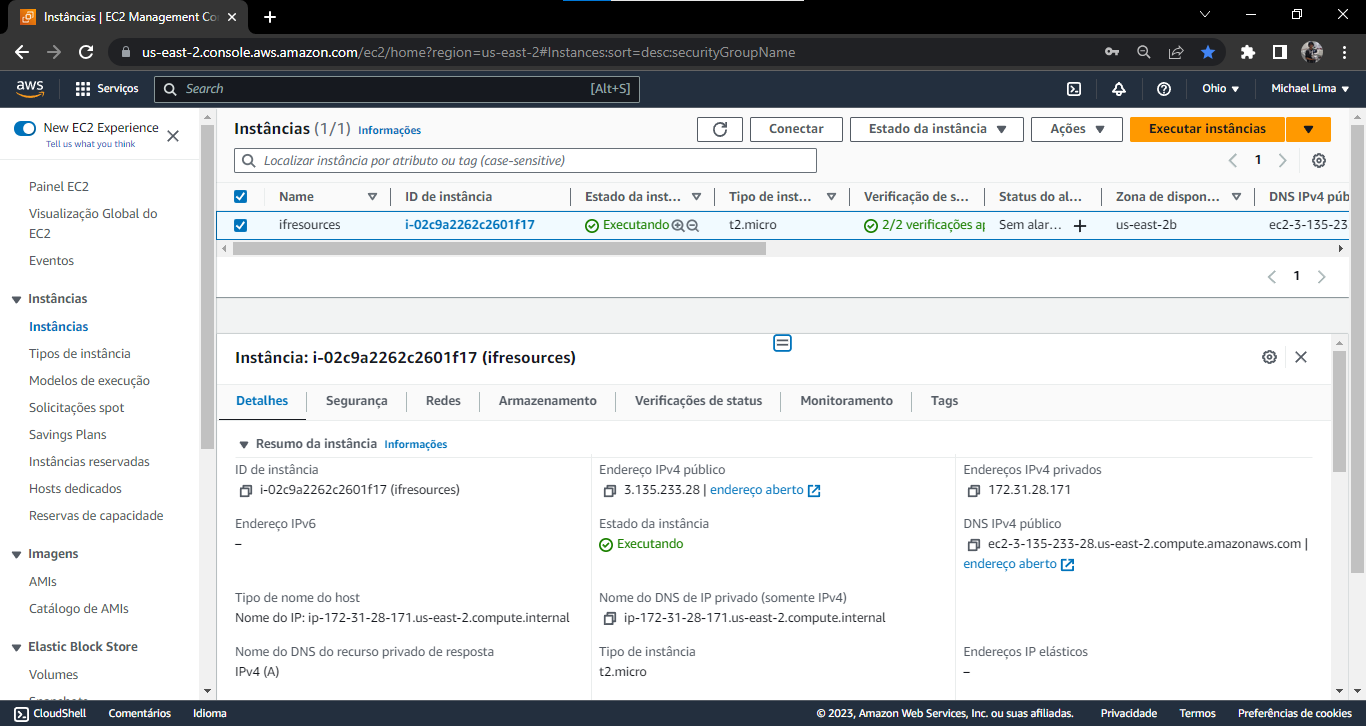
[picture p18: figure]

Figura 25 – Imagem do painel de configuração da imagem EMQX que está rodando na AWS

Capítulo 3. Implementação Final | 33

Figura 26 – Imagem do painel de configuração do site que está hospedado na hostinger

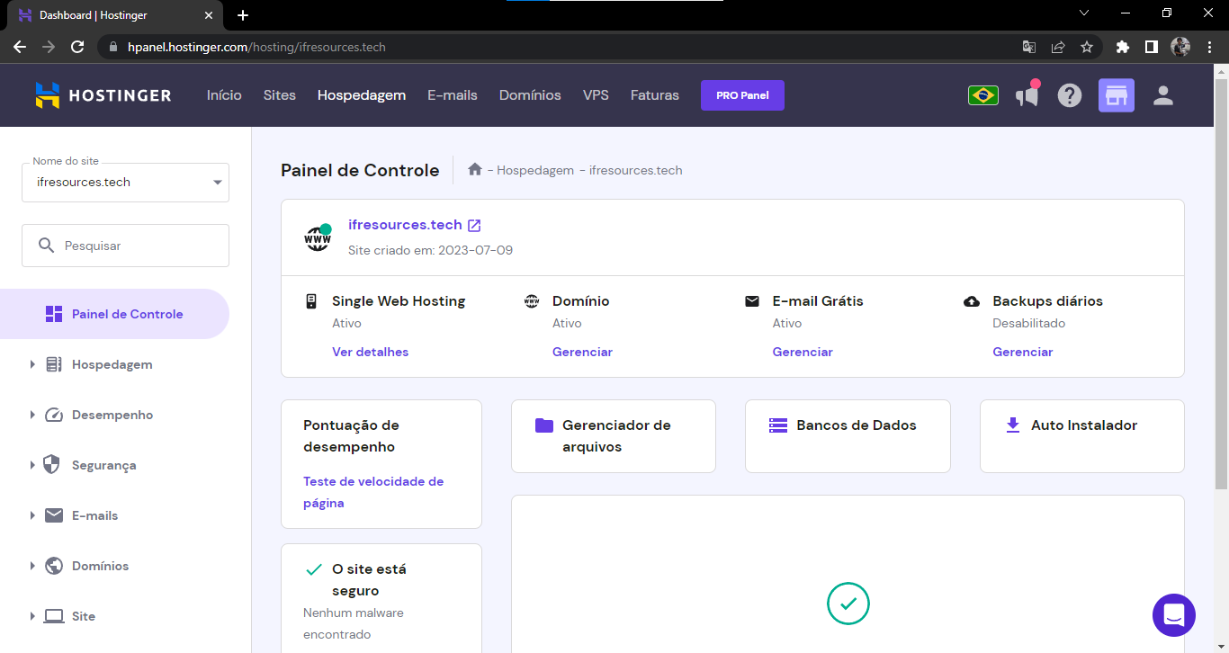
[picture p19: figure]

3.1.3 Passo 3 - Construção do hardware

Conectaremos ao Lora 32 os sensores de temperatura e umidade DHT22, sensor de nível de água Diy 4 e um transmissor infra-vermelho HX-53.

- Nessa imagem podemos ver a parte interna do equipamento que tem na parte superior:

a antena do Lora 32, o sensor de temperatura e umidade DHT22 e o transmissor infravermelho HX-53. No meio temos conectado na protoboard de 400 pontos o Heltec Lora 32 e o sensor de nível de água Diy 4 e tudo conectado através de jumpers.

Figura 27 – Imagem da parte interna do equipamento

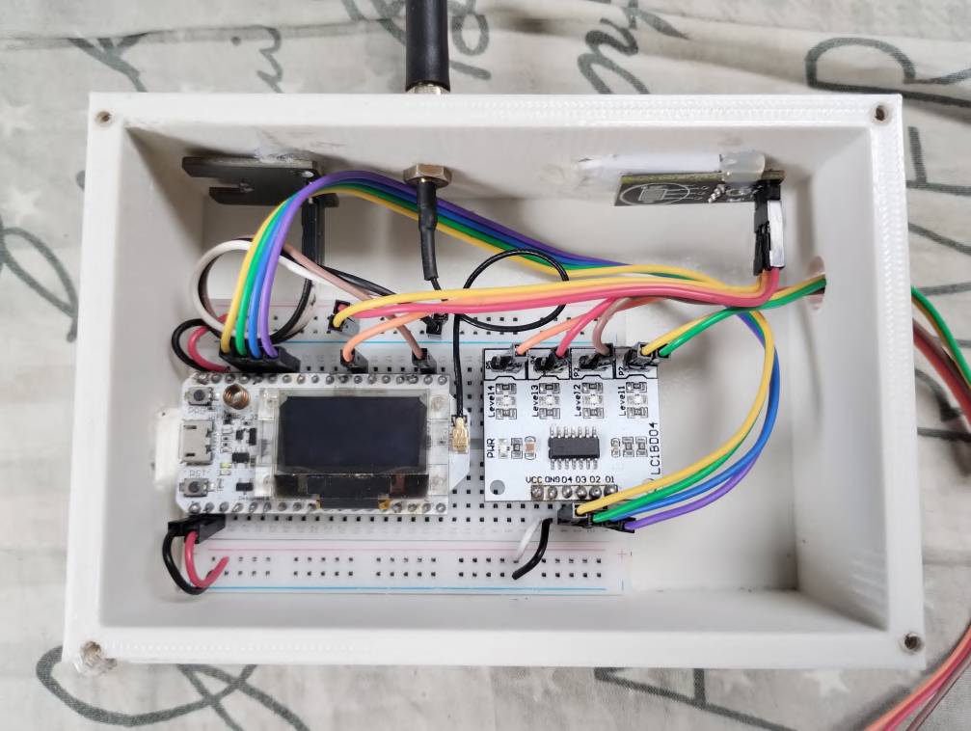
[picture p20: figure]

Capítulo 3. Implementação Final | 34
- Nessa imagem podemos ver na parte superior do equipamento a antena de comu-

nicação do Lora 32 no centro dela, na direita o sensor de temperatura e umidade DHT22 e na esquerda o led do transmissor infravermelho HX-53.

Figura 28 – Imagem da parte superior do equipamento

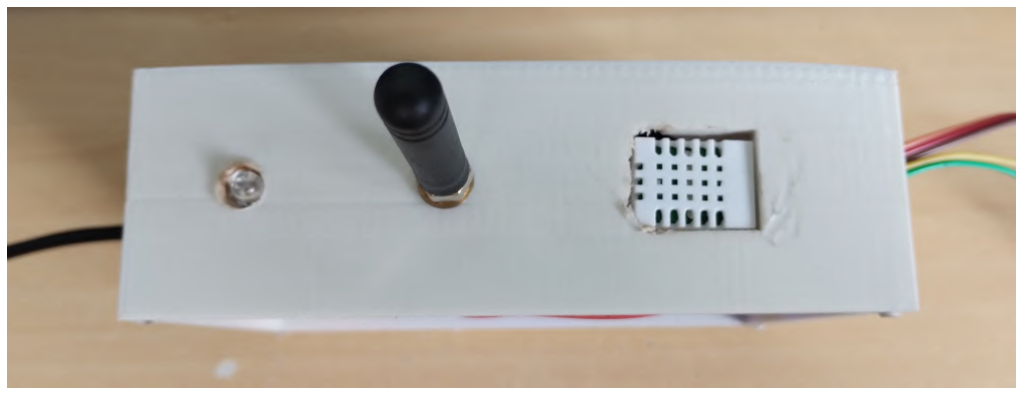
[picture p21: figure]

3.1.3.1 Sensor de temperatura e umidade DHT22

Utilizaremos a porta 25 do LORA-32, definido na função "void setup(void)". O valor será lido como char (similar a string). As informações serão recebidas pelo micro-controlador e enviadas na tela e atribuidas no MQTT na função "void loop(void)".

- Nessa imagem podemos ver circulado em vermelho o sensor de temperatura e umidade

DHT22 na parte superior direita da case e também circulado em vermelho um fio laranja conectado na porta 25 do Lora 32.

Figura 29 – Imagem da conexão do sensor de tempereatura e umidade DHT22 no Lora 32

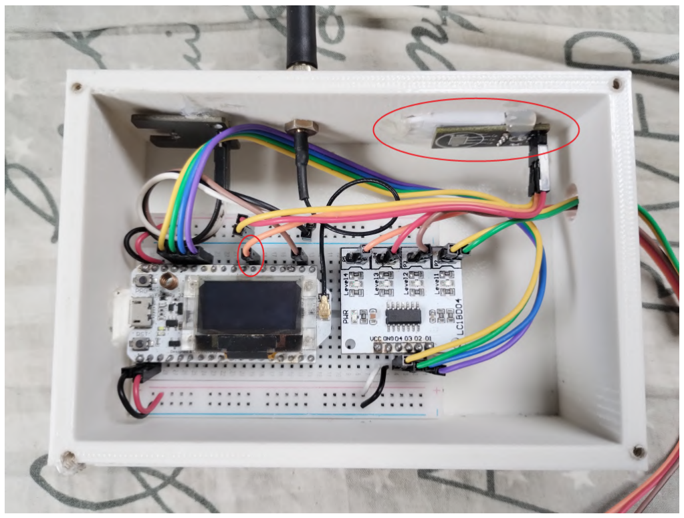
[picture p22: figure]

Capítulo 3. Implementação Final | 35

3.1.3.2 Transmissor Infra-vermelho HX-53

Utilizaremos a porta 13 do LORA-32, definido no arquivo "PinDefinitionsAnd-More.h". definindo a função callback, há uma sequência de condições “if e else if” dentro de cada uma delas, há um bloco condicional com um comando referentes ao sendRaw que é um array dos comandos infravermelhos captados pelos controles do ar-condicionado, ou seja, cada array é um comando do controle do ar-condicionado.

- Nessa imagem podemos ver circulado em vermelho o transmissor infra-vermelho

HX-53 na parte superior esquerda da case e também circulado em vermelho um fio marrom conectado na porta 13 do Lora 32.

Figura 30 – Imagem da conexão do transmissor infra-vermelho HX-53 no Lora 32

3.1.3.3 Sensor de Nível de Água Diy 4 (LC1BD04)

Utilizaremos as portas 36, 37, 38 e 39 do LORA-32. O sensor de nível de água Diy 4 funciona praticamente por meio de um curto-circuito entre os terminais dos níveis das placas, utilizando a condutibilidade elétrica da água. Os valores serao lidos pelo micro-controlador apenas como 1 e 0 e o papel de envia-los para MQTT é atribuido na função "void loop(void)".

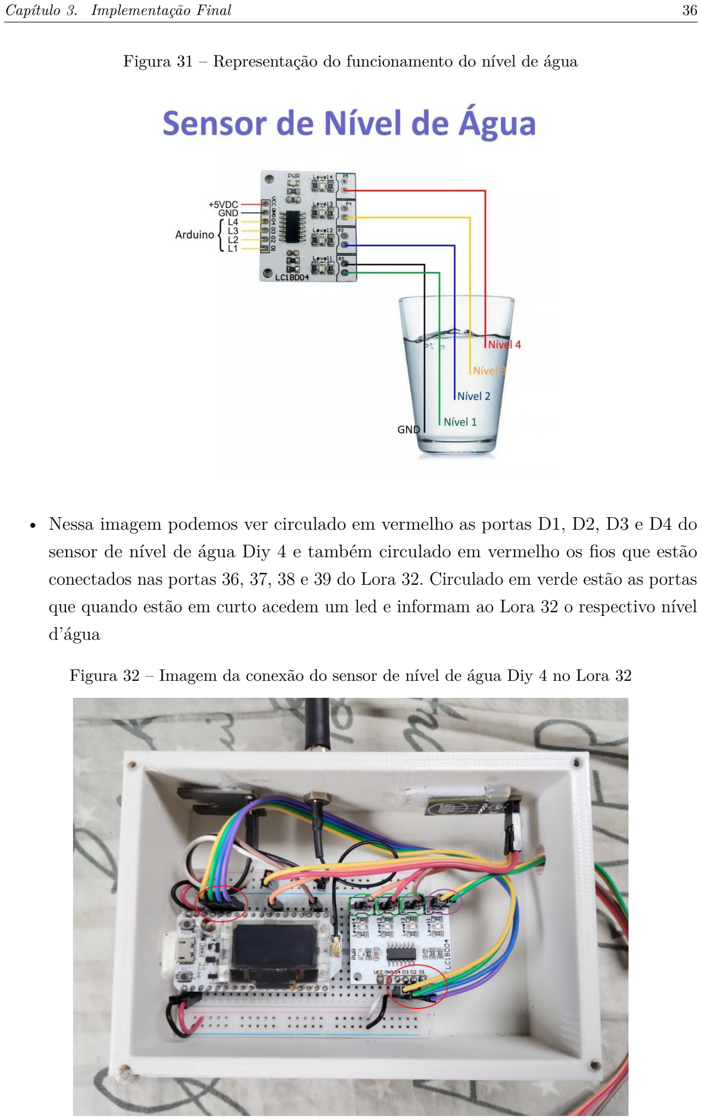
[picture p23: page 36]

Capítulo 3. Implementação Final | 36

Figura 31 – Representação do funcionamento do nível de água

- Nessa imagem podemos ver circulado em vermelho as portas D1, D2, D3 e D4 do

sensor de nível de água Diy 4 e também circulado em vermelho os fios que estão conectados nas portas 36, 37, 38 e 39 do Lora 32. Circulado em verde estão as portas que quando estão em curto acedem um led e informam ao Lora 32 o respectivo nível d’água

Figura 32 – Imagem da conexão do sensor de nível de água Diy 4 no Lora 32

Capítulo 3. Implementação Final | 37

## 3.2 Produto Final

Aqui temos o produto final, o equipamento proposto pelo projeto em sua verão final, com a tampa parafusada com 4 parafuros de fenda e com uma abertura para a tela do Lora 32 que mostra a tela inicial quando é ligado e se conectado ao Wi-Fi e quando conectado, mostra a informação de temperatura na tela. No site mostra além da informação de temperatura, as informações de umidade e nível d’água. Com ele conectado a rede, o usuário pode controlar o ar-condionado, deixando o equipamento apontado para o receptor infra-vermelho do aparelho e entrando no site na página de controle.

- Nessa imagem vemos o produto final, ou seja, o equipamento finalizado e pronto

para uso.

Figura 33 – Imagem do Equipamento Finalizado

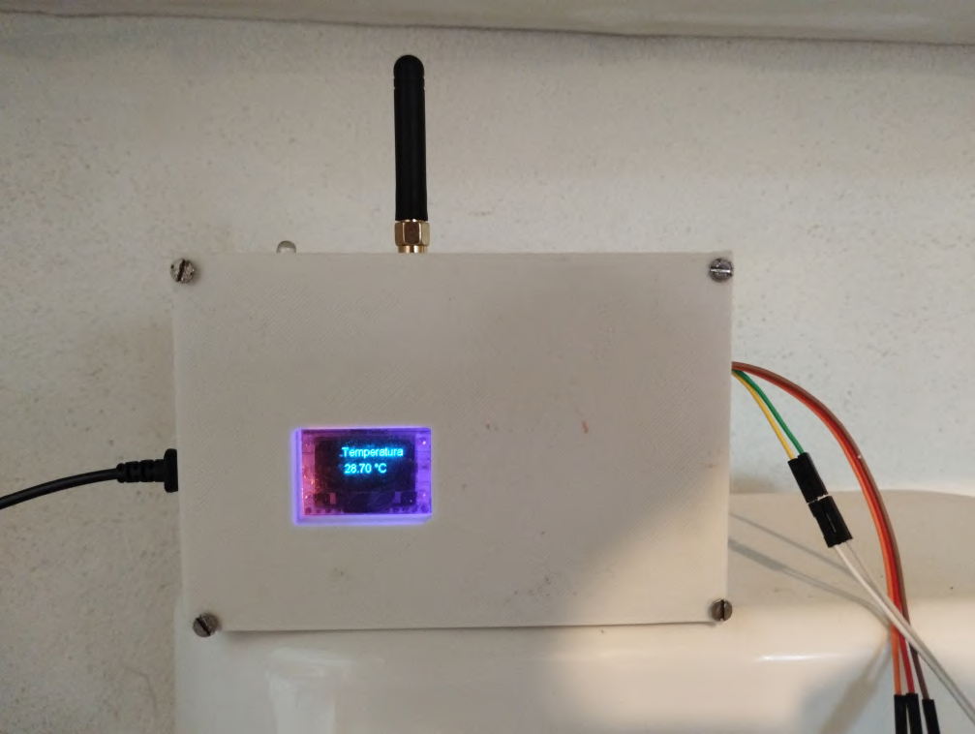
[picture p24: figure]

38

# 4 CONSIDERAÇÕES FINAIS

Esse projeto tinha como intuito facilitar a vida dos estudantes do Instituto Federal do Rio de Janeiro - Campus Niterói por meio de monitores de temperatura, umidade e nível de água e controles de ar-condicionado, a partir de tecnologias como C/C++, HTML, CSS, JavaScript e Docker.

O projeto também tem como objetivo incentivar os alunos e professores do IFRJ Campus Niterói o aprimoramento e inserção no mundo da eletrônica, das tecnologias IoT e a Pesquisa e Extensão no dia a dia dessa instituição de ensino. O projeto também buscar ajudar nos estudos de IoT, prototipação eletrônica, Impressão 3D e desenvolvimento de site ligados à equipamentos eletrônicos construidos pelas próprias explorando a cultura maker e filosofia do "Do It Yourself (DIY)".

Os códigos escritos e utilizados são de domínio público e estão todos disponíveis no GitHub no perfil dos criadores desse projeto. O github dos criadores e desenvolvedores do projeto. Gabriel Sales Rodrigues, Michael Monteiro de Lima e Miryam Estábila Nogueira de Souza se encontram no final das referências deste artigo.

39

# 5 REFERÊNCIAS

- ESP32 LORA WIFI SX1278. Gustavo Teixeira. Usinainfo. (https://www.usinainfo.com.br/blog/esp32-lora-wifi-sx1278/)
- PROJETO ESP32 COM DISPLAY OLED E SENSOR AM2302 DHT22 MEDINDO

TEMPERATURA E UMIDADE. Gustavo Teixeira. Usinainfo. (https://www.usinainfo.com.br/blog/projeto-esp32-com-display-oled-e-sensor-am2302-dht22-medindo-temperatura-e-umidade/)

- CONHECENDO A PLACA WIFI LORA ESP32 (433MHZ / 868MHZ / 915MHZ).

Euler Oliveira. Master Walker. (https://blogmasterwalkershop.com.br/embarcados/esp32/conhecendo-a-placa-wifi-lora-esp32-433mhz-868mhz-915mhz)

- ESP32 WITH DHT11/DHT22 TEMPERATURE AND HUMIDITY SENSOR

USING ARDUINO IDE. Alan Miller. Random nerd tutorials. (https://randomnerdtutorials.com/esp32-dht11-dht22-temperature-humidity-sensor-arduino-ide/)

- LUIZSTATION MQTT PUBLISHER. Luiz Felipe. GitHub. (https://github.com/luizsoliveira/arduinoExamples/blob/main/LuizStationMQTTPublisher/LuizStationMQTTPublisher.ino)
- LUIZSTATION MQTT TEMPDHT11. Luiz Felipe. GitHub. (https://github.com/luizsoliveira/arduinoExamples/blob/main/LuizStationMQTTTempDHT11/LuizStationMQTTTempDHT11.ino)
- AIR CONDITIONERS: RECORDING LONG INFRARED REMOTE CONTROL

SIGNALS WITH ARDUINO. AnalysIR. (https://www.analysir.com/blog/2014/03/19/air-conditioners-problems-recording-long-infrared-remote-control-signals-arduino)

- CAPTURANDO E ENVIANDO CÓDIGOS INFRAVERMELHO DE AR-CONDICIONADO

COM O ARDUINO - SENDRAW. Danilo Queiroz Barbosa. (https://www.youtube.com/watch?v=fj2UHC1LVfw&t=3s)

- COMO FAZER CONTROLE REMOTO DE TV COM ARDUINO PRO MINI.

Marlon Nardi. (https://www.youtube.com/watch?v=-1SKYm74tjY&ab_channel=MarlonNardi)

- ESP32 LAB 01 - DISPLAY OLED, SENSOR DHT22 E HORA VIA NTP SERVICE.

EasyTrom Labs. (https://www.youtube.com/watch?v=843zY-stQaw&ab_channel=EasyTromLabs)

- RECEPTOR INFRAVERMELHO (IR) - CURSO DE ARDUINO 41. Marlon Nardi. (https://www.youtube.com/watch?v=sax7Mcfbj7I&t=781s)
- MQTT WEB DASHBOARD | MQTT WEB APP USING HTML , CSS AND JAVA

SCRIPT. High Voltages. (https://www.youtube.com/watch?v=rlnhd67PV-M&list=PLTd8mu_xCkvxMpibB1C1FWmk-0KfJDvjv&index=3)

- ACESSE DADOS VIA MQTT NO NAVEGADOR - IEC69. Internet e Coisas. (https://www.youtube.com/watch?v=oR2J0ar6cZQ&t=788s)
- COMO COLOCAR UM SITE NO AR (2023). Hostinger Brasil. (https://www.youtube.com/watch?v=3_bWVGv9Iho&t=196s&ab_channel=HostingerBrasil)
- HOW TO POINT DOMAIN NAME TO WEB HOSTING. Hostinger Academy. (https://www.youtube.com/watch?v=UAsYeTL8cZc&ab_channel=HostingerAcademy)
- O QUE É DOMÍNIO E HOSPEDAGEM E COMO COLOCAR SEU SITE NO AR

COM A HOSTINGER. Rafaella Ballerini. (https://www.youtube.com/watch?v=7ZC3_QwKo5Q&t=861s&ab_channel=RafaellaBallerini)

- JAVASCRIPT MQTT CLIENT: A BEGINNER’S GUIDE TO MQTT.JS. Shifan

Yu. EMQ Technologies Inc. (https://www.emqx.com/en/blog/mqtt-js-tutorial)

Capítulo 5. Referências | 40
- A QUICKSTART GUIDE TO USING MQTT OVER WEBSOCKET. Shifan Yu.

EMQ Technologies Inc. (https://www.emqx.com/en/blog/connect-to-mqtt-broker-with-websocket)

- AWS ACADEMY CLOUD FOUNDATIONS. Amazon Web Services INC. (https://aws.amazon.com/pt/training/awsacademy/)
- TCC. Gabriel Sales. Github. (https://github.com/gaabpng/TCC)
- IFResources. Michael Lima. Github. (https://github.com/MichaelLimaDeveloper/IFResources)

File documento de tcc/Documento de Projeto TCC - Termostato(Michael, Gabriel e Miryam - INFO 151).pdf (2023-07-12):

# Termostato de Controle e Monitoramento de Temperatura

Disciplina: Projeto de TCC I Prof.ª. Helvio J. Junior

INSTITUTO FEDERAL DO RIO DE JANEIRO - CAMPUS NITERÓI CURSO TÉCNICO DE INFORMÁTICA INTEGRADO AO ENSINO MÉDIO

GABRIEL SALES RODRIGUES
MICHAEL MONTEIRO DE LIMA
MIRYAM ESTÁBILA NOGUEIRA DE SOUZA

## TERMOSTATO DE CONTROLE E MONITORAMENTO DE TEMPERATURA

Projeto de Conclusão de Curso apresentado ao Instituto Federal de Educação, Ciência e Tecnologia do Rio de Janeiro Campus Niterói como requisito parcial para obtenção de notas das disciplinas de Projeto Final de Curso (I e II) e para obtenção da colação de grau do Curso Técnico de Informática Integrado ao Ensino Médio.

Orientador: DSc. Luiz Felipe Silva Oliveira.

Mensões: Pedro Henrique Biega Lopes Bandeira e Miguel Ramos Gil.

NITERÓI/RJ
2022

Resumo

O trabalho de conclusão de curso, termostato de controle e monitoramento de temperatura tem como objetivo controlar e monitorar a temperatura das salas de aula ou laboratórios do campus. Seu objetivo é tornar prático o controle e monitoramento da temperatura, evitar eventuais problemas de saúde para frequentadores do campus, e incentivar as pessoas a prática e desenvolvimento da eletrônica, tecnologias IoT e a Pesquisa e Extensão.

Palavras-Chaves: Eletrônica, Prototipação e IoT.

Abstract

The course completion work, control thermostat and temperature monitoring aims to control and monitor the temperature of classrooms or campus laboratories. Its objective is to make temperature control and monitoring practical, to avoid possible health problems for campus visitors, and to encourage people to practice and develop electronics, IoT technologies and Research and Extension.

Keywords: Electronics, Prototyping and IoT.

LISTA DE FIGURAS

Figura 1 – Brainstorming | 11
Figura 2 – Trello | 11
Figura 3 – Modelo Conceitual do projeto | 13
Figura 4 – Interface do Wokwi com o protótipo | 16
Figura 5 – Bibliotecas utilizadas | 16
Figura 6 – Código do segundo protótipo | 17
Figura 7 – Interface de controle e monitoramento no MQTT dashboard | 19
Figura 8 – Interface do aplicativo | 20
Figura 9 – Modelo 3D no Tinkercad | 21
Figura 10 – Circuitos Eletrônicos | 22
Figura 11 – Primeiro protótipo físico do projeto | 23

LISTA DE TABELAS

Tabela de funcionalidades previstas | 14
Tabela de orçamento do projeto. | 24

LISTA DE SIGLAS E ABREVIAÇÕES

TCC | Trabalho de Conclusão de Curso
IDE | Integrated Development Environment
IOT | Internet of Things
MQTT | Message Queuing Telemetry Transport
HTML | HyperText Markup Language
CSS | Cascading Style Sheets
ESP 32 Espressif 32
LoRa 32 | Long Range 32
DHT | Detector for humidity and temperature
SCT | Sensor de corrente e tensão
OLED | Organic Light Emitting Diode
C++ | Classes Plus Plus
Wi-Fi | Wireless Fidelity
REQ | Requisito

SUMÁRIO

1. INTRODUÇÃO | 9
1.1 Contextualização e Motivação | 9
1.2. Objetivos | 10
1.2.1 Objetivo Geral | 10
1.2.2. Objetivos Específicos | 10
1.3 Metodologia | 10
2. TÍTULO DO TEMA DO PROJETO | 13
2.1. Descrição Geral da Proposta | 13
2.2. Lista de Requisitos (Funcionalidades) previstas | 14
2.3. Processo de Prototipagem | 16
2.3.1 Primeiro protótipo do projeto | 16
2.3.2 Protótipo versão MQTT(Segundo protótipo do projeto) | 17
2.3.3 Configuração do MQTT Dashboard | 19
2.3.4 Protótipo do gabinete impresso em 3D | 20
2.3.5 Protótipo Físico | 22
2.4. Orçamento do Projeto | 24
3. REFERÊNCIAS BIBLIOGRÁFICAS | 25
3.1. Fontes das referências em sites, fóruns e artigos na internet | 25
3.2. Fontes das referências em vídeos na internet | 25

### 1. INTRODUÇÃO

### 1.1 Contextualização e Motivação

O IFRJ campus Niterói possui vários laboratórios com equipamentos que têm que trabalhar e que precisam ser operados em condições climáticas de acordo com a especificação técnica. relatos da equipe técnica apontam que constantemente alguns equipamentos apresentam defeitos por não estarem operando em uma temperatura adequada.
Essa perda dos equipamentos por esse motivo bem como o monitoramento desses ambientes demanda tempo e custos para a instituição.
Visando solucionar esse problema, alguns alunos do semestre 2022.1 começaram a idealizar uma solução para tentar minimizar o problema reportado acima. Portanto, as seguintes propostas de projeto foram definidas: A prototipação de uma central de monitoramento e controle do ar-condicionado.
Portanto, o protótipo a ser desenvolvido é fazer um termostato na qual é possível monitorar a temperatura ambiente do ar condicionado (Temperatura e Energia) e também o controle do ar-condicionado(Ligar/Desligar e Controle de Temperatura). Esse controle e monitoramento será feito utilizando protocolo MQTT e o Aplicativo MQTT Dashboard. Usaremos o Heltec Lora 32 que é uma versão de esp32 com o display OLED embutido junto de componentes eletrônicos como: Sensores de Temperatura (DHT11 e DHT22), Sensor de Corrente (SCT-013), e o Transmissor Infravermelho (HX-53). O circuito eletrônico deste projeto será feito com uma protoboard, resistores e jumps. Tudo isso dentro de um gabinete (uma caixa provavelmente) feita em impressão em 3D.
O público alvo do projeto é os discentes, docentes e equipe de manutenção para ajudar a manter o bem estar de todos no campus. Também há a questão de que se algum ar-condicionado estiver com problema, o indivíduo usuário do aplicativo saberá antes mesmo de entrar na sala, em caso de até mesmo de evitar problemas de saúde como um eventual choque térmico por exemplo.
A importância desse projeto é para facilitar o controle da temperatura dos ar-condicionado e monitorar a temperatura dos ambientes de sala em tempo real. A ideia é evitar que os alunos, docentes e servidores tenham problemas de saúde por conta de dias quentes e o mau uso do aparelho. Evitar o desperdício de energia do campus e desgastes do aparelho.

### 1.2. Objetivos

### 1.2.1 Objetivo Geral

A proposta deste trabalho é o desenvolvimento de um medidor de temperatura de ambientes para monitorar o funcionamento do ar-condicionado e a temperatura do ambiente. No IFRJ campus Niterói, existe a necessidade de controlar a temperatura das salas de aulas e também manter os alunos do campus em uma temperatura ideal, bem como prover meios de economizar a energia da escola.

### 1.2.2. Objetivos Específicos

Medidor de temperatura de sala, assim podendo saber se a temperatura, a temperatura da saída do ar-condicionado e saber se está ligado ou não. Isso será feito com um Heltec Lora 32 e os sensores DHT11, DHT22 e SCT-013. Também será feito o controle da temperatura do ar-condicionado usando protocolo MQTT, aplicativo MQTT Dashboard e o Transmissor infravermelho HX-53.

Os objetivos específicos que auxiliaram no atendimento do objetivo geral deste trabalho são os seguintes:

⮚ | Permitir a leitura (medidor) da temperatura das salas usando sensores DHT11, DHT22 e
| SCT-013
⮚ | Permitir o controle do ar condicionado através do envio de informações para executar ações de
| aumento, acionamento e diminuição usando um transmissor infravermelho HX-53.

### 1.3 Metodologia

Como esse projeto foi iniciado no período 2022.1 pelos alunos. Inicialmente o projeto era um “2 em 1” com uma Sirene e um Termostato para a entrega no final do curso. Porém com a reprovação de Michael no 5º período, houve uma divisão do projeto. A Sirene ficou com Pedro e Miguel e o termostato com Michael que se juntou a Miryam para realizá-lo. A metodologia aplicada é a de desenvolver a ideia dentro das aulas de projeto final I e assim desenvolver um protótipo de um produto junto de um documento. Os passos dados foram o desenvolvimento da ideia com o grupo; a pesquisa dos componentes a serem usados, com orientações do prof. Luiz Felipe e usando as aulas de Hardwares Programáveis I e II como base; escolha dos componentes; a compra dos componentes; prototipação.

1. Ideação: A Necessidade de monitorar e de controlar a temperatura das salas de aula em dias de calor para que o ar condicionado seja ligado ou não, evitando o desperdício de energia, desgaste do aparelho e problemas de saúde de todos do campus devido ao calor ou ao mau uso. Também com o objetivo de controlar a temperatura das salas de aula e manter os alunos do campus em uma temperatura ideal e também, economizar energia da escola, equilibrando entre o conforto dos que estão na aula e a economia de energia da escola. Essa temperatura definida pela escola é de em média 22 a 23 graus.

— Brainstorming


— Trello


2. Definição das funcionalidades a serem implementadas: As seguintes funcionalidades a serem aplicadas serão o monitoramento e controle. No caso, monitoramento da temperatura ambiente de uma sala ou laboratório no campus; monitoramento da temperatura de saída do ar-condicionado; monitoramento da corrente e de on/off do ar-condicionado; e controle de temperatura do ar-condicionado, além da função de ligar e desligar.

3. Prototipação: O protótipo trata-se de um conjunto dos componentes DHT11 para monitoramento da temperatura ambiente, DHT22 para monitoramento da temperatura do ar-condicionado, SCT-013 para monitoramento da corrente e de on/off do ar condicionado, um transmissor infravermelho HX-53 para controle do ar-condicionado, e um microcontrolador Heltec Lora 32 que tem uma tela onboard para mostrar as temperaturas monitoradas. A junção de todos esses componentes resulta em uma central de controle e monitoramento do ar-condicionado, a ideia é juntar todos esses componentes em uma case. Óbvio, nem todos os componentes será possível ficarem juntos, já que o sensor de temperatura que vai monitorar o ar-condicionado, não pode está junto do sensor de temperatura que irá monitorar a temperatura ambiente, porém o circuito que vai fazer a conexão de todos os componentes e os microcontrolador precisa necessariamente estarem juntos em uma central. Até para uma questão de organização.
4. Configuração do Ambiente de Desenvolvimento: Os ambientes de trabalho do projeto incluem alguns programas como o Arduino IDE, Wokwi, TinkerCad e o Ultimaker cura como plataformas de desenvolvimento do projeto. Basicamente o Arduino IDE é um ambiente e desenvolvimento para programação em linguagem C e C++ para placas de desenvolvimento como o arduino, esp8266, esp32, lora 32, etc. Nessa IDE possuem diversas bibliotecas com foco em inúmeras aplicações, mas no caso desse projeto usaremos bibliotecas com foco em IoT e Suporte a componentes. O Wokwi é um simulador online de diversas placas de desenvolvimento, incluindo o esp32 e que sua IDE é similar ao Arduino IDE. O TinkerCad além de ser um simulador online com foco em arduino, ele tem diversos recursos e entre eles um de modelagem 3D. De fato é básico, porém é o suficiente para o projeto. E o Ultimaker cura é um software de fatiamento 3D que serve para importar um projeto 3D e converter ou adaptar o projeto para impressão.
5. Implementação das Funcionalidades: Usaremos o protocolo MQTT para enviar as informações para um broker e usaremos o MQTT dashboard como interface de monitoramento e controle do produto. Teremos a relação de publisher e subscribe entre os sensores de monitoramento e controle que estarão ligados ao esp32 e que terão suas informações exibidas no MQTT dashboard. O controle será feito da mesma forma, só que o inverso, haverá botões na interface de usuário simulado os botões de um controle de ar-condicionado que quando acionado, enviará o comando para o transmissor infravermelho HX-53 para determinar alguma ação do ar-condicionado.

6. Implementação de Melhorias: As melhorias poderão ser broker MQTT, que podemos implementar um próprio do campus como proposto pelo orientador do projeto. Também podemos melhorar na questão de, invés de depender do conjunto MQTT como um todo (Protocolo MQTT e MQTT Dashboard), mas sim, usar uma interface web com HTML e CSS. É uma solução opcional caso não der certo o conjunto MQTT.
- Modelo Conceitual do projeto:


### 2. TÍTULO DO TEMA DO PROJETO

### 2.1. Descrição Geral da Proposta

A proposta do termostato é ser uma central de monitoramento e controle da temperatura de uma sala ou laboratório do campus. Esse monitoramento e controle será feito pela internet usando tecnologias IoT como o protocolo MQTT que é compatível com o Lora 32. A linguagem de programação a ser utilizada é o C++ usando uma IDE (Integrated Development Environment) chamada Arduino IDE, que dá suporte além dessa linguagem, dá suporte a bibliotecas que iremos utilizar como DHT sensor library, ESP8266 and ESP32 OLED driver for SSD1306 displays, WiFi, PubSubClient, IRremote e drivers como USB Silicon Labs CP210x para UART Bridge VCP que dão suporte ao Lora 32 e os todos os componentes que utilizaremos no protótipo como o DHT11, DHT22 e SCT-013, que são sensores de monitoramento. E o transmissor infravermelho HX-53, que transmite informações que também podem ser comandos. Todos esses componentes serão interligados em uma protoboard usando jumpers e usaremos alguns resistores de 10kΩ para os sensores de monitoramento descritos acima e também no Transmissor infravermelho HX-53. Tudo isso estará dentro de um gabinete/case que será impresso em 3D usando tecnologias como o thingiverse, tinkercad e o ultimaker cura. O primeiro é um site de projetos em 3D para usarmos como base para a construção da case, o segundo é um software de modelagem 3D web para modelar o projeto, e o terceiro é um software de fatiamento 3D usando para imprimir de fato o projeto em uma impressora 3D.

A ideia é desenvolver uma interface no mqtt dashboard, usando os protocolos mqtt para se comunicar ao broker mqtt para podemos controlá-los remotamente usando o Lora 32 com os componentes descritos no último parágrafo. O layout do aplicativo será da seguinte forma, lá haverá 3 caixas de exibição que mostram: 1. Temperatura ambiente, 2. Temperatura do ar-condicionado, 3. Corrente do ar-condicionado. Depois, haverá 3 botões: 1. Liga e desliga,
2. Aumentar a temperatura, 3. Diminuir temperatura. Cada caixa de exibição e cada botão haverá um tópico definido dentro do código que será colocado no Lora 32 para que o aplicativo possa se comunicar com o Lora 32. Esses tópicos podemos chamar de protocolos MQTT, pois, através deles que a informação é enviada ao um broker, que é o chamado publisher. E também que o aplicativo possa receber essa informação que está no broker, que é chamado de subscriber. Também acontece o caminho contrário deste tráfego de informação, que aí no caso o publisher será o aplicativo e o subscriber o Lora 32, geralmente usado para comandos de controle e atribuídos a botões no aplicativo.

### 2.2. Lista de Requisitos (Funcionalidades) previstas

ID Requisito | Descrição
REQ1 -Medir a temperatura ambiente | A Temperatura ambiente será medida através de um Sensor DHT11 conectado ao Lora 32 por jumps junto de resistor de 10kΩ. O resistor e o Lora32 estarão conectados em uma protoboard
REQ2 -Medir a temperatura do | A temperatura do ar-condicionado vai ser medida através de um Sensor DHT22, que tem maior precisão se comparado ao DHT22, conectado ao Lora 32 por jumps junto de resistor de 10kΩ. O resistor e o Lora 32 estarão conectados em uma protoboard. O sensor estará posicionado na frente do

ar-condiciona do | duto de ar do ar-condicionado para que possa monitorar a temperatura do ar-condicionado.
REQ3 -Medir a Corrente do ar-condiciona do | A corrente do Ar-condicionado será medida através de um sensor chamado SCT-013 que é um sensor de corrente não invasivo, ou seja, ele vai monitorar a corrente que é consumida pelo ar-condicionado. Ele será ligado com resistores de 10kΩ (muito provavelmente) em uma protoboard e será conectado ao Lora 32 através da mesma.
REQ4 - Se conectar ao uma rede e enviar ass informações ao Broker MQTT | O Lora 32 vai se conectar a uma rede de internet e se conectar ao broker MQTT. Depois, ele pegará as informações coletadas pelos sensores descritos e enviará as informações para o Broker MQTT através de um tópico. No aplicativo MQTT Dashboard, ele pegará as informações que estão sendo enviadas para aquele tópico e vai exibir em uma interface. Nessa interface haverá informações de monitoramento como: temperatura ambiente, temperatura do ar-condicionado, corrente utilizada pela o ar-condicionado.
REQ5 - O controle do ar-condiciona do | Usando um transmissor infravermelho HX-53, serão transmitidos sinais em infravermelho que vai emular os botões do ar-condicionado. O comando será dado pelo aplicativo MQTT dashboard e esse comando será enviado a partir de um tópico MQTT para o Lora 32 que vai receber e executar o comando para o transmissor infravermelho HX-53.


### 2.3. Processo de Prototipagem

### 2.3.1 Primeiro protótipo do projeto:

Os testes foram feitos inicialmente pelo simulador Wokwi, como mostrado na imagem abaixo, esse teste abaixo é somente para a verificação e entendimento do funcionamento de uma parte do projeto. No caso um sensor dht22 mostrando a temperatura coletada do “ambiente”. A ideia é pegar a essa informação e jogar para o broker MQTT para ser exibido no MQTT dashboard, porém isso o que é demonstrado abaixo foi um primeiro “esboço” do projeto.

- Interface do Wokwi com o protótipo:
- Bibliotecas utilizadas:

### 2.3.2 Protótipo versão MQTT(Segundo protótipo do projeto):

Nesse protótipo, pretendemos ir mais além. No primeiro protótipo era relativamente simples, somente coletando as informações captadas pelo sensor dht22 e assim mostrando as informações de temperatura e umidade do ambiente no monitor serial e no display OLED. Usando como base o primeiro protótipo, foi desenvolvido o segundo protótipo com um código que se conecta a uma rede Wi-Fi com internet e que faz o envio das informações captadas pelo sensor dht22 para um broker MQTT, essa ação é chamada de publisher e assim podendo ser coletadas através de um subscriber. No código é mostrado que o envio das informações é feito através de um tópico MQTT e usando um aplicativo como o MQTT dashboard, criamos uma interface onde podemos colocar o tópico em uma caixa de exibição do aplicativo para justamente exibir as informações enviadas.

- Código do segundo protótipo:


- Interface de controle e monitoramento no MQTT dashboard:


### 2.3.3 Configuração do MQTT Dashboard:

A configuração do MQTT Dashboard consiste em criar uma aba para onde ficará a sua interface e durante a criação dessa aba você deve colocar o endereço e a porta do broker MQTT que está sendo utilizado. No caso deste protótipo o endereço “broker.hivemq.com” com a porta “1883”. Depois disso deve-se criar botões que serão as caixas de exibição para cada tópico MQTT definido no código, nesse caso, um para o Tempo, um para a Temperatura e um para Umidade. Em breve a ideia é desenvolver mais 3 botões, um para ligar e desligar o ar-condicionado, um para aumentar a temperatura e um para diminuir. Tudo isso utilizado de tópicos MQTT que farão alguma ação definida no código que estará dentro do Lora 32 que irá comandar o HX-53 que é o transmissor infravermelho. Irei estar disponibilizando um documento com o passo-a-passo com imagens e instruções de configuração do aplicativo MQTT Dashboard. Abaixo segue o link desse documento e algumas imagens da interface desenvolvida.

Link do documento: <<Documento ainda a ser redigido e disponibilizado>>

- Interface do aplicativo:


### 2.3.4 Protótipo do gabinete impresso em 3D:

O gabinete foi desenvolvido por Michael Lima e Pedro Henrique para comportar todos os componentes necessários. Que são a protoboard, o Lora 32, sensores dht11, dht22, sct-013 e HX-53. Ele foi desenvolvido em uma solução web chamada tinkercad em uma aba do programa específica para modelagem 3D. Suas respectivas medidas são: 17cm de largura, 6cm de profundidade e 6cm de altura. Ela se abrirá ao meio, onde estará comportando seus componentes de dará acesso aos mesmos. Abaixo estão algumas imagens do modelo em 3D.


- Modelo 3D no Tinkercad:

### 2.3.5 Protótipo Físico:

Abaixo está uma parte do circuito eletrônico que haverá nesse termostato, as imagens abaixo são: O circuito eletrônico no simulador Fritzing, O Esquema eletrônico e o PCB do circuito. Por enquanto, nesse protótipo abaixo só tem dois sensores de monitoramento que são o DHT11 e DHT22 com 2 resistores de 10kΩ, um para cada sensor. Isso conectado à uma protoboard que está conectada no Lora 32. Logo abaixo há um protótipo que tem os componentes descritos anteriormente com a adição de transmissor infravermelho HX-53 que ainda não está sendo utilizado. Assim como no Wokwi, esses esquemas abaixo e as fotos do protótipo abaixo são só um “esboço”, tendo muita coisa que será mudada e melhorada, mas mantendo a ideia central e os componentes.

- Circuitos Eletrônicos:


- Primeiro protótipo físico do projeto com um Lora 32 e com o transmissor infravermelho HX-53:

Referências aos protótipos: TCC DO TERMOSTATO. Michael Lima. GitHub. Disponível em: <<https://github.com/MichaelLimaDeveloper/TCC-do-Termostato>>, acesso feito em 18/12/2022.

### 2.4. Orçamento do Projeto

Basicamente abaixo é uma tabela com todos os gastos com o projeto até agora. O valor de cada produto e o subtotal de todos. Todos os links são de onde realmente foram comprados a maioria dos itens, não incluindo o frete caso o produto tenha sido comprado pela internet. Aqui foi contando o valor de cada componente e não o valor bruto com a soma de frete dos itens ou reposição de componentes.

Descrição (c/link) | Qtd | Valor unit. | Subtotal | Situação
Heltec Lora 32 (https://shopee.com.br/SX1276-SX1278-ESP32-LoRa-868MHz-915MHz-433MHz-0.96-Polegadas-Display-OLED-Azul-Kit-Placa-De-Desenvolvimento-Bluetooth-i.550918841.147693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) | 1 | R$ 92,21 | R$ 92,21 | Comprado
Cabo USB (https://shopee.com.br/Cabo-USB-UNO-R3-De-30cm-Micro-Nano-3.0-Para-mini-Mega-2560-A-B-E-arduino-i.550918841.16136370920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) | 1 | R$ 6,66 | R$ 98,87 | Comprado
Protoboard (https://shopee.com.br/Protoboard-830-Pontos-Para-Arduino-i.313674734.7378920882) | 1 | R$ 17,39 | R$ 116,26 | Comprado
Resistor 10K(conjunto (https://shopee.com.br/10-Unidades-de-Resistores-de-Filme-de-Carbono-1-4w-5-Eletr%C3%B4nica-Rob%C3%B3tica-para-Protoboard-PCB-Ardu%C3%ADno-i.413370384.21446984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) com 10) | 1 | R$ 1,09 | R$ 117,35 | Comprado
Sensor De Temperatura E Umidade Dht11 Arduino (https://shopee.com.br/DHT22-ou-DHT11-Sensor-De-Temperatura-E-Umidade-DHT-11-compativel-com-Arduino-ESP32-NodeMcu-e-Raspberry-i.318953938.11091764925) | 1 | R$ 8,98 | R$ 126,33 | Comprado
Sensor De Temperatura E Umidade Dht22 Arduino (https://shopee.com.br/DHT22-ou-DHT11-Sensor-De-Temperatura-E-Umidade-DHT-11-compativel-com-Arduino-ESP32-NodeMcu-e-Raspberry-i.318953938.11091764925) | 1 | R$ 29,98 | R$ 156,31 | Comprado
Sensor De Corrente Dc Não Invasivo Sct-013 (https://shopee.com.br/Sensor-de-corrente-n%C3%A3o-invasivo-i.460782516.14863642771) | 1 | R$ 35,00 | R$ 191,31 | Comprado
Kit transmissor e receptor infravermelho HX-53 e Ky-022 (https://shopee.com.br/Modulo-Emissor-e-Receptor-Infravermelho-para-Controle-Remoto-Arduino-Protoboard-Robotica-Automacao-Eletronica-Robby-i.413370384.18359146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) | 1 | R$ 7,25 | R$ 198,56 | A Caminho

### 3. REFERÊNCIAS BIBLIOGRÁFICAS

### 3.1. Fontes das referências em sites, fóruns e artigos na internet

CONHECENDO A PLACA WIFI LORA ESP32 (433MHZ / 868MHZ / 915MHZ). Euler Oliveira. Master Walker. Disponível em: <<https://blogmasterwalkershop.com.br/embarcados/esp32/conhecendo-a-placa-wifi-lora-esp 32-433mhz-868mhz-915mhz>>, (https://blogmasterwalkershop.com.br/embarcados/esp32/conhecendo-a-placa-wifi-lora-esp32-433mhz-868mhz-915mhz) acesso feito em 18/11/2022.

PROJETO ESP32 COM DISPLAY OLED E SENSOR AM2302 DHT22 MEDINDO TEMPERATURA E UMIDADE. Usinainfo. Disponivel em <<https://www.usinainfo.com.br/blog/projeto-esp32-com-display-oled-e-sensor-am2302-dht22-medindo-temperatura-e-umidade/>>, (https://www.usinainfo.com.br/blog/projeto-esp32-com-display-oled-e-sensor-am2302-dht22-medindo-temperatura-e-umidade/) acesso feito em 18/11/2022.

ESP32 LAB 01 – DISPLAY OLED, SENSOR DHT22 E HORA VIA NTP SERVICE. Easytromlabs. Disponível em: <<https://easytromlabs.com/esp32/esp32-lab-01-display-oled-sensor-dht22-e-hora-via-ntp-service/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,5%20%25%20de%20acertos %20na%20leitura.>>, (https://easytromlabs.com/esp32/esp32-lab-01-display-oled-sensor-dht22-e-hora-via-ntp-service/?print=print) acesso feito em 18/11/2022.

ESP32 WITH DHT11/DHT22 TEMPERATURE AND HUMIDITY SENSOR USING ARDUINO IDE. Alan Miller. Random nerd tutorials. Disponível em: <<https://randomnerdtutorials.com/esp32-dht11-dht22-temperature-humidity-sensor-arduino-ide/>>, (https://randomnerdtutorials.com/esp32-dht11-dht22-temperature-humidity-sensor-arduino-ide/) acesso feito em 18/11/2022.

LUIZSTATION MQTT PUBLISHER. Luiz Felipe. GitHub. Disponível em: <<https://github.com/luizsoliveira/arduinoExamples/blob/main/LuizStationMQTTPublisher/L uizStationMQTTPublisher.ino>>, (https://github.com/luizsoliveira/arduinoExamples/blob/main/LuizStationMQTTPublisher/LuizStationMQTTPublisher.ino) acesso feito em 28/11/2022.

LUIZSTATION MQTT TEMPDHT11. Luiz Felipe. GitHub. Disponível em: <<https://github.com/luizsoliveira/arduinoExamples/blob/main/LuizStationMQTTTempDHT11/LuizStationMQTTTempDHT11.ino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>>, (https://github.com/luizsoliveira/arduinoExamples/blob/main/LuizStationMQTTTempDHT11/LuizStationMQTTTempDHT11.ino) acesso feito em 07/12/2022.

### 3.2. Fontes das referências em vídeos na internet

COMO FAZER CONTROLE REMOTO DE TV COM ARDUINO PRO MINI. Marlon Nardi. Disponível em:
<<https://www.youtube.com/watch?v=-1SKYm74tjY&ab_channel=MarlonNardi>>, acesso feito em 28/11/2022.

ESP32 LAB 01 – DISPLAY OLED, SENSOR DHT22 E HORA VIA NTP SERVICE. EasyTrom Labs. Disponível em: <<https://www.youtube.com/watch?v=843zY-stQaw&ab_channel=EasyTromLabs>>, acesso feito em 07/12/2022.

RECEPTOR INFRAVERMELHO (IR) - CURSO DE ARDUINO #41.
Marlon Nardi. Disponível em:
<<https://www.youtube.com/watch?v=sax7Mcfbj7I&t=781s >>, acesso feito em 20/12/2022.

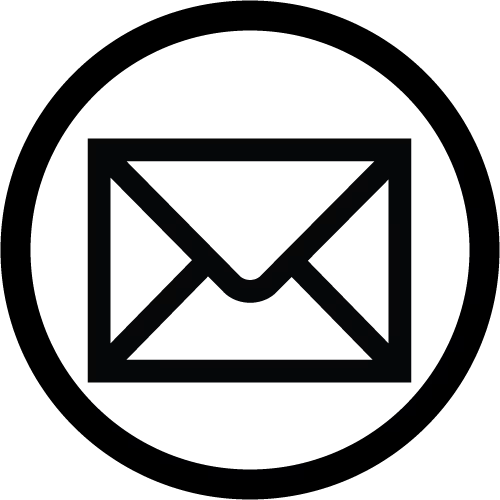
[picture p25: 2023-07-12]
ifresources site/imagens/email.png

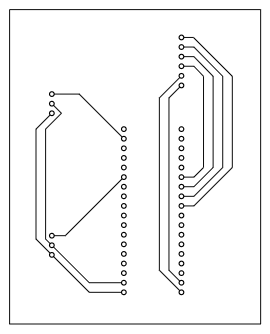
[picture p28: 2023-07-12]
Circuito eletrônico, PCB e Impressão 3D/EasyEDA/PCB_PCB TCC_2023-07-11.png

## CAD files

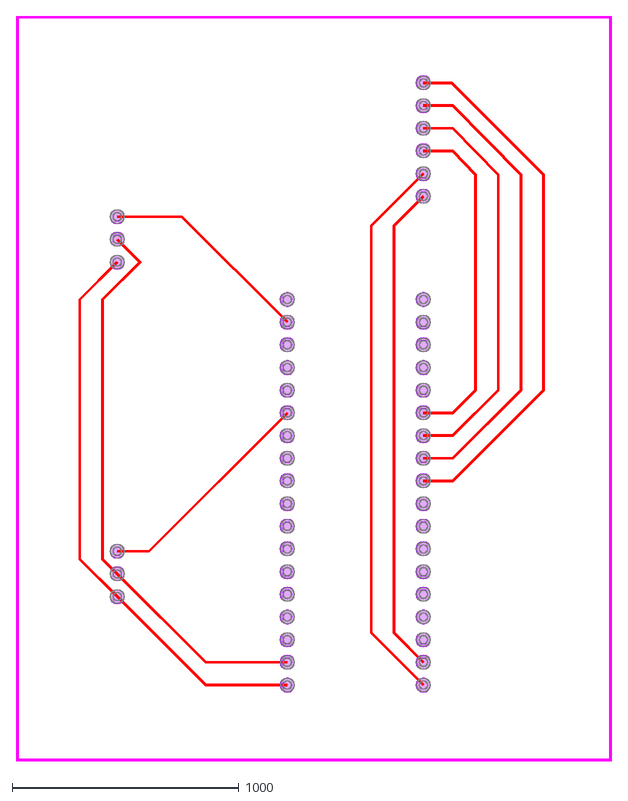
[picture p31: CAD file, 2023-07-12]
Circuito eletrônico, PCB e Impressão 3D/EasyEDA/PCB TCC_2023-07-11.dxf
2625.0 x 3285.0

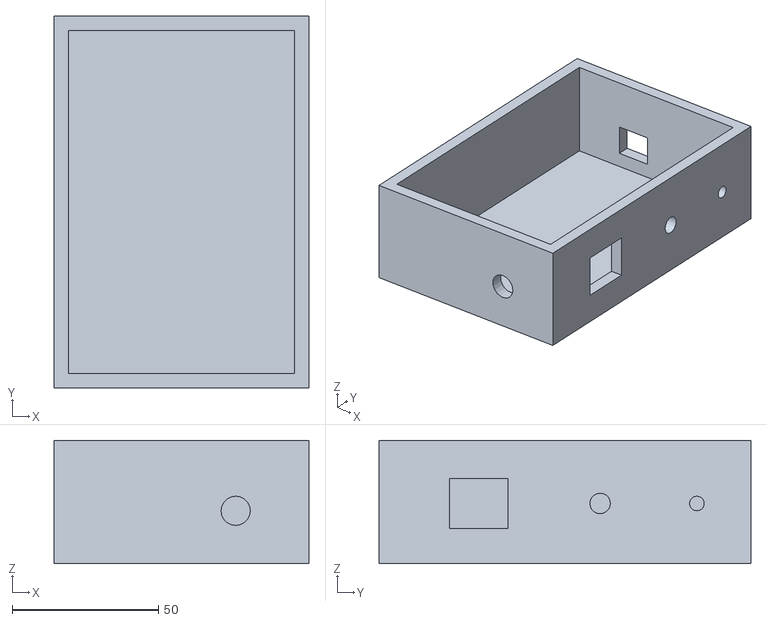
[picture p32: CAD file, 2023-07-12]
Circuito eletrônico, PCB e Impressão 3D/TinkerCad/caixa.stl
87.0 x 127.0 x 42.0

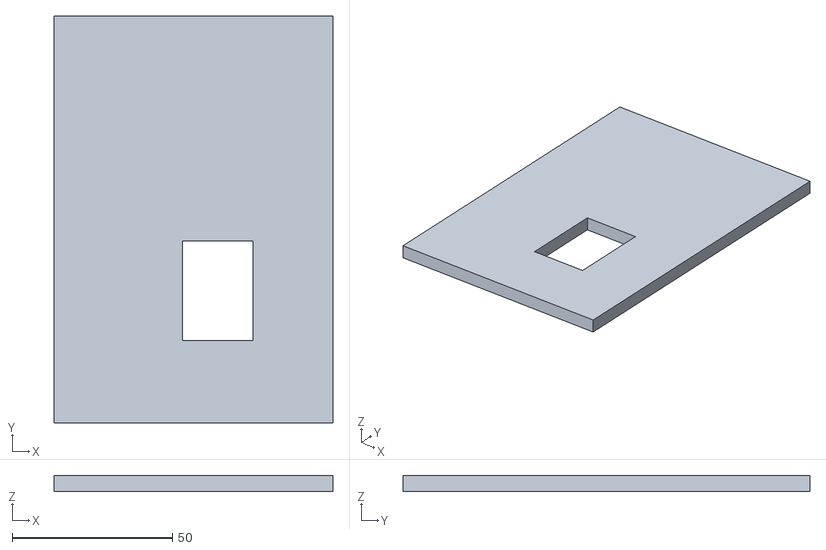
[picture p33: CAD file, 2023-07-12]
Circuito eletrônico, PCB e Impressão 3D/TinkerCad/tampa.stl
87.0 x 127.0 x 5.00

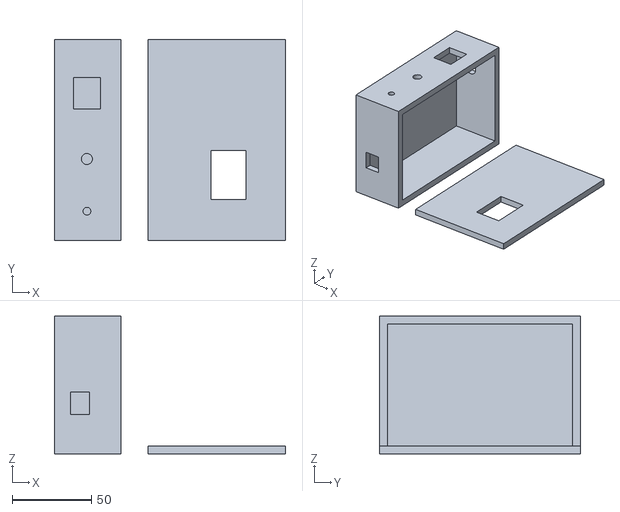
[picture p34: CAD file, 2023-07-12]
Circuito eletrônico, PCB e Impressão 3D/TinkerCad/caixa para tcc completa.stl
146.0 x 127.0 x 87.0

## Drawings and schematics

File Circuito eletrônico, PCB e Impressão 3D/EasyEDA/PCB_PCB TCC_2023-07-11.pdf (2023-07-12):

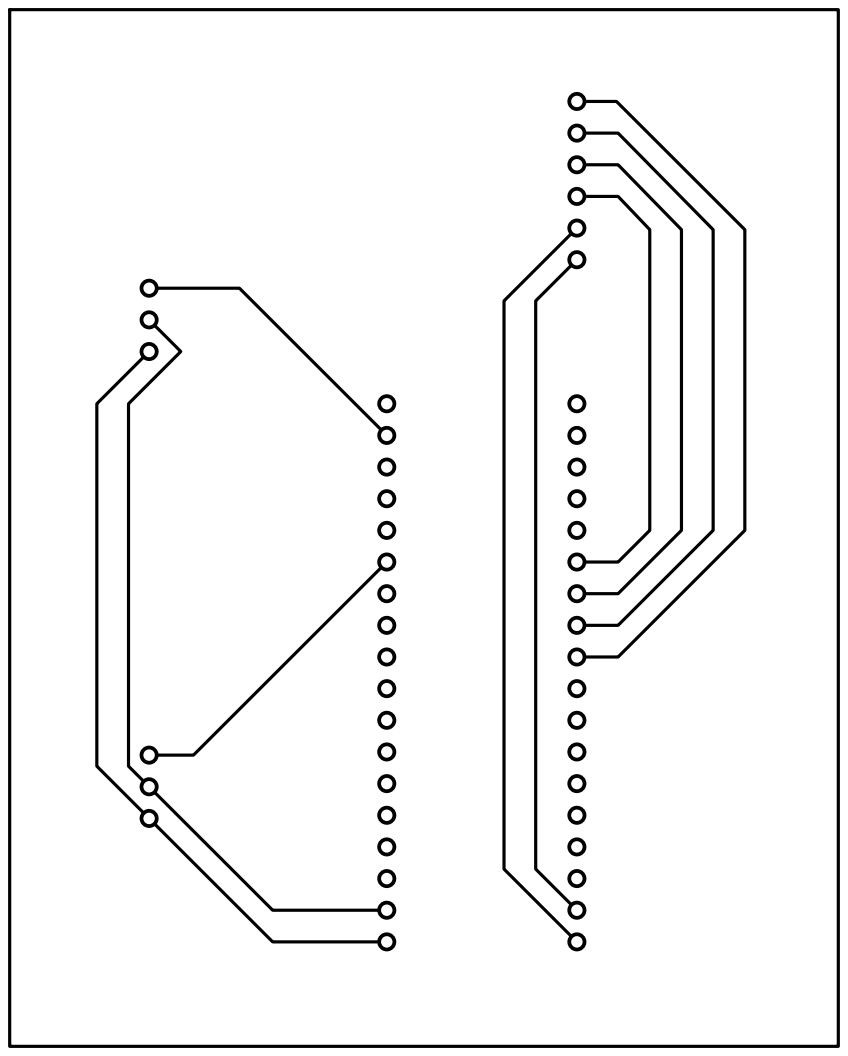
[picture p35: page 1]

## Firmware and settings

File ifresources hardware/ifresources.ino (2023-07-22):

//Incluindo o arquivo da biblioteca que define a porta que será utilizada pelo transmissor infravermelho
#include "PinDefinitionsAndMore.h"

//Incluindo as bliotecas utilizadas
#include "WiFi.h"
#include "PubSubClient.h"
#include "ESPmDNS.h"
#include "DHTesp.h"
#include "heltec.h"
#include "IRremote.hpp"

//Definindo a Rede que o equipamento vai ser conectada
#define NET_SSID "LABProv"
#define NET_PASSWORD "labprov1"

//Definindo os parâmetros do protocolo MQTT como ID, Broker, Porta e os Tópicos
#define MQTT_ID "ifresources-tcc-lora32"
#define MQTT_BROKER "broker.emqx.io"
#define MQTT_PORT 1883
#define MQTT_MILLIS_TOPIC "tcc_ifresources_millis"
#define MQTT_SECONDS_TOPIC "tcc_ifresources_seconds"
#define MQTT_DHT_TEMP_TOPIC "tcc_ifresources_temp"
#define MQTT_DHT_HUMD_TOPIC "tcc_ifresources_humd"
#define MQTT_NIVEL_TOPIC "tcc_ifresources_nivel"
#define MQTT_SENDRAW_TOPIC "tcc_ifresources_sendraw_manage"

//Definindo objeto para a conexão Wi-Fi e criação do cliente MQTT
WiFiClient espClient; 
PubSubClient MQTT(espClient);

//Definindo as Strings usadas para o envio das informações
char millis_str[10] = "";
char seconds_str[10] = "";
char temp_str[10] = "";
char humd_str[10] = "";
char nivel_str[10] = "";

//Definindo a banda de frequência de comunicação sem fio e definindo objeto para o DHT22 
#define BAND    915E6
DHTesp dht;

//Variavéis do Nivel d'água
using namespace std;
bool isPressed = "";
int nivel = 0;
int buttonState = 0;

//Variavéis do Sensor DHT22
float currentTemp;
float currentHumidity;

// Variável global para armazenar o tempo inicial
unsigned long tempoInicial;

//Definindo as funções
void getTemp();
void getHumidity();
void getNivel();
void sendPacket();

//Função que conecta o Lora 32 em algum Wi-Fi
void setupWifi(){
  if(WiFi.status() == WL_CONNECTED){
    return;
  } else {

    Serial.println();
    Serial.print("Connecting to ");
    Serial.println(NET_SSID);
  
    WiFi.begin(NET_SSID, NET_PASSWORD);

    while (WiFi.status() != WL_CONNECTED){
        delay(500);
        Serial.print(".");
    }

    Serial.println("");
    Serial.println("WiFi connected");
    Serial.println("IP Address:");
    Serial.println(WiFi.localIP());
    }
}

//Função que conecta o Lora 32 no Broker MQTT
void setupMQTT(){

    MQTT.setServer(MQTT_BROKER, MQTT_PORT);
    MQTT.setCallback(mqtt_ifresources_callback); 

    while (!MQTT.connected()){
        Serial.print("- MQTT Setup: Tentando se conectar ao Broker MQTT: ");
        Serial.println(MQTT_BROKER);

        if(MQTT.connect(MQTT_ID)){
            Serial.println("- MQTT Setup: Conectado com sucesso");
            Serial.println(" ");
             MQTT.subscribe(MQTT_SENDRAW_TOPIC);
        } else {
            Serial.println("- MQTT Setup: Falha ao se conectar, tentando novamente em 2s");
            delay(2000);
        }
    }
}

//Função da Temperatura
void getTemp()
{

  float temperature = dht.getTemperature();

  if (temperature != currentTemp) {
    currentTemp = temperature;

    digitalWrite(LED, HIGH);
    delay(500);
    digitalWrite(LED, LOW);
    delay(500);
  }
  delay(1000);
}

//Função da Umidade
void getHumidity()
{

  float humidity = dht.getHumidity();

  if (humidity != currentHumidity) {
    currentHumidity = humidity;
    
    digitalWrite(LED, HIGH);
    delay(500);
    digitalWrite(LED, LOW);
    delay(500);                
  }
  delay(1000);
}

//Função do Nível d'água
void getNivel()
{

    if (digitalRead(36) == 1)
    {
        nivel = 4;
    }
    
    else if (digitalRead(37) == 1)
    {
        nivel = 3;
    }

    else if (digitalRead(38) == 1)
    {
        nivel = 2;
    }

    else if (digitalRead(39) == 1)
    {
        nivel = 1;
    }
    else
    {
        nivel = 0;
    }

}

//Função setup aonde é definido a configuração da primeira tela e a pinagem de alguns componentes
void setup(void)
{
    /*O baudrate no monitor serial é (115200)*/
    tempoInicial = millis();
    pinMode(LED, OUTPUT);

    Heltec.begin(true, true, true , true , BAND);
    /*(
      true = Habilita o Display, 
      true = Heltec.Heltec.Heltec.LoRa Disable, 
      true = Habilita debug Serial, 
      true = Habilita o PABOOST, 
      BAND = Frequência BAND.
    )*/

    Heltec.display->init();
    Heltec.display->setContrast(255);
    Heltec.display->clear();
    Heltec.display->setFont(ArialMT_Plain_24);
    Heltec.display->drawString(0, 0, "IFresources");
    Heltec.display->setFont(ArialMT_Plain_16);
    Heltec.display->drawString(0, 25, "@ifrjniteroi");
    Heltec.display->setFont(ArialMT_Plain_10);
    Heltec.display->drawString(0, 45, "Conectando ao Wi-Fi...");
    Heltec.display->display();
    delay(1000);

    dht.setup(25, DHTesp::DHT22); 
  
    currentTemp = dht.getTemperature();
    currentHumidity = dht.getHumidity();

    pinMode(36, INPUT);
    pinMode(37, INPUT);
    pinMode(38, INPUT);
    pinMode(39, INPUT);

    setupWifi();
    setupMQTT();
}

//Função loop aonde é definido a configuração da segunda tela que mostra a temperatura e aonde é enviado as informações para o broker
void loop(void)
{
  getTemp();
  getHumidity();
  getNivel();

  unsigned long tempoAtual = millis();
  unsigned long segundos = (tempoAtual - tempoInicial) / 1000;

  Heltec.display->clear();
  Heltec.display->setTextAlignment(TEXT_ALIGN_LEFT);
  Heltec.display->setFont(ArialMT_Plain_16);
  Heltec.display->drawString(30, 5, "Temperatura");
  Heltec.display->drawString(33, 30, (String)currentTemp);
  Heltec.display->drawString(78, 30, "°C");
  Heltec.display->display();

  Serial.println("Tempo em Milissegundos: " + (String)millis());
  Serial.println("Tempo em Segundos: " + (String)segundos);  
  Serial.println("Temperatura: " + (String)currentTemp + "°C");
  Serial.println("Umidade: " + (String)currentHumidity + "%");
  Serial.println("Nivel da Água: " + (String)nivel);
  Serial.println("---");

  sprintf(millis_str, "%d", millis());
  MQTT.publish(MQTT_MILLIS_TOPIC, millis_str);

  sprintf(seconds_str, "%s", (String)segundos);
  MQTT.publish(MQTT_SECONDS_TOPIC, seconds_str);

  sprintf(temp_str, "%s", (String)currentTemp );
  MQTT.publish(MQTT_DHT_TEMP_TOPIC, temp_str);

  sprintf(humd_str, "%s", (String)currentHumidity );
  MQTT.publish(MQTT_DHT_HUMD_TOPIC, humd_str);

  sprintf(nivel_str, "%s", (String)nivel);
  MQTT.publish(MQTT_NIVEL_TOPIC, nivel_str);

  setupWifi();
  setupMQTT();
  MQTT.loop();
  delay(1000);
}

//Função Callback aonde é configurado os comandos do ar-condicionado de ligar, desligar, aumentar e diminuir a temperatura.
void mqtt_ifresources_callback(char* topic, byte* payload, unsigned int length)
{
  String msg;
  Serial.print("- MQTT Callback Topic: ");
  Serial.println(topic);

  for (int i = 0; i < length; i++)
  {
    char c = (char)payload[i];
    msg += c;
  }

  if (msg.equals("P1"))
    {
      #if !(defined(__AVR_ATtiny25__) || defined(__AVR_ATtiny45__) || defined(__AVR_ATtiny85__))
  
      const uint16_t rawData[] = {3064, 1624, 452, 1128, 452, 1124, 456, 360, 456, 360, 456, 360, 456, 1124, 456, 360, 452, 364, 452, 1128, 456, 1124, 456, 360, 456, 1124, 456, 360, 452, 364, 452, 1124, 456, 1124, 456, 360, 456, 1124, 456, 1124, 456, 360, 456, 360, 456, 1124, 452, 364, 456, 360, 456, 360, 452, 1128, 456, 360, 456, 360, 452, 360, 460, 360, 452, 364, 452, 360, 456, 360, 452, 364, 456, 360, 456, 360, 456, 360, 456, 360, 456, 360, 456, 360, 456, 360, 456, 360, 456, 360, 456, 360, 452, 364, 452, 360, 456, 1124, 456, 360, 456, 360, 456, 360, 456, 360, 456, 360, 456, 360, 456, 360, 456, 360, 456, 360, 456, 360, 452, 364, 452, 364, 452, 364, 452, 364, 452, 364, 452, 364, 452, 364, 452, 360, 456, 364, 452, 360, 456, 364, 452, 360, 456, 360, 452, 364, 452, 364, 452, 364, 456, 360, 452, 364, 452, 364, 456, 360, 452, 364, 456, 360, 452, 364, 452, 360, 452, 368, 452, 364, 452, 360, 456, 360, 452, 364, 452, 364, 452, 364, 456, 360, 456, 360, 452, 364, 456, 360, 456, 360, 456, 360, 452, 364, 452, 364, 456, 360, 456, 356, 456, 336, 480, 360, 456, 360, 456, 360, 456, 360, 456, 360, 456, 1124, 456, 360, 456, 1124, 456, 360, 452, 364, 452, 1124, 456, 1128, 452, 360, 456, 4456, 3060, 1628, 452, 1124, 456, 1124, 456, 360, 456, 360, 456, 360, 456, 1124, 456, 360, 456, 360, 452, 1128, 456, 1124, 456, 360, 452, 1128, 452, 360, 456, 360, 456, 1124, 456, 1124, 456, 360, 452, 1128, 456, 1124, 452, 364, 452, 364, 452, 1124, 456, 360, 456, 360, 456, 1124, 456, 360, 456, 360, 456, 360, 456, 360, 456, 360, 456, 360, 452, 364, 452, 364, 452, 364, 452, 364, 456, 360, 452, 364, 452, 364, 452, 364, 452, 364, 452, 364, 452, 360, 456, 1124, 456, 360, 456, 360, 452, 1128, 456, 360, 456, 360, 456, 1124, 452, 1128, 452, 364, 452, 364, 452, 364, 452, 364, 452, 364, 452, 360, 456, 1124, 456, 1124, 456, 360, 456, 1124, 452, 364, 456, 360, 456, 360, 456, 360, 452, 1128, 456, 1124, 452, 360, 456, 360, 456, 360, 456, 360, 456, 360, 452, 364, 456, 360, 456, 360, 456, 360, 456, 360, 456, 360, 456, 360, 452, 364, 456, 360, 452, 364, 452, 364, 452, 364, 452, 364, 452, 364, 452, 364, 452, 360, 456, 360, 452, 364, 456, 360, 456, 360, 456, 360, 456, 360, 456, 360, 456, 360, 456, 360, 452, 364, 456, 360, 452, 364, 452, 1128, 452, 360, 456, 360, 456, 360, 456, 1124, 456, 360, 456, 1124, 456, 360, 456, 360, 456, 1124, 456, 360, 456, 1120, 460, 1124, 452};
      IrSender.sendRaw(rawData, sizeof(rawData) / sizeof(rawData[0]), NEC_KHZ);
  
      Serial.println(F("Send NEC 16 bit address=0xFB04 and command 0x08 with exact timing (16 bit array format)"));
      Serial.flush();
      delay(1000);
      
        
      Serial.println("- MQTT Sub Conn: (P1) Ligar Ar-condicionado Received");
      Serial.println("---");

      #endif  
    }

   else if (msg.equals("P0"))
    {
      #if !(defined(__AVR_ATtiny25__) || defined(__AVR_ATtiny45__) || defined(__AVR_ATtiny85__))
  
      const uint16_t rawData[] = {3064, 1620, 456, 1124, 456, 1124, 456, 360, 456, 360, 456, 360, 456, 1124, 456, 360, 452, 364, 452, 1124, 460, 1124, 452, 360, 456, 1124, 456, 360, 456, 364, 452, 1124, 456, 1124, 456, 360, 452, 1128, 456, 1124, 452, 364, 452, 364, 456, 1124, 452, 360, 460, 356, 460, 356, 456, 1124, 456, 360, 456, 360, 456, 360, 456, 360, 456, 360, 456, 360, 452, 364, 456, 360, 456, 360, 456, 360, 456, 360, 456, 360, 456, 360, 456, 360, 456, 360, 452, 364, 452, 360, 460, 360, 456, 356, 456, 360, 456, 1124, 456, 360, 456, 360, 456, 360, 456, 360, 452, 364, 456, 360, 452, 364, 456, 360, 456, 360, 456, 360, 456, 356, 456, 364, 452, 360, 456, 360, 456, 360, 456, 360, 456, 360, 456, 360, 456, 360, 456, 360, 456, 360, 456, 360, 456, 360, 452, 364, 456, 360, 456, 360, 452, 360, 456, 364, 456, 356, 456, 360, 456, 360, 456, 360, 456, 360, 456, 360, 456, 360, 456, 360, 456, 360, 452, 364, 452, 364, 456, 360, 452, 364, 452, 364, 452, 360, 456, 360, 456, 364, 452, 360, 456, 360, 456, 360, 456, 360, 456, 360, 452, 364, 456, 360, 456, 360, 452, 364, 452, 364, 456, 356, 456, 364, 456, 1120, 456, 360, 456, 1124, 456, 360, 456, 360, 456, 1124, 456, 1124, 456, 360, 456, 3972, 3088, 1596, 484, 1096, 480, 1100, 480, 336, 480, 336, 452, 364, 480, 1100, 480, 336, 480, 336, 480, 1096, 484, 1096, 484, 332, 480, 1100, 480, 336, 480, 336, 480, 1100, 480, 1100, 480, 336, 480, 1096, 480, 1100, 480, 336, 480, 336, 484, 1096, 480, 336, 480, 336, 480, 1100, 480, 336, 480, 336, 480, 332, 484, 332, 484, 332, 480, 336, 480, 336, 480, 336, 480, 336, 480, 336, 480, 336, 480, 336, 484, 332, 480, 336, 480, 336, 480, 336, 480, 336, 480, 336, 480, 336, 480, 336, 476, 1100, 480, 336, 484, 332, 480, 1100, 452, 1128, 480, 336, 480, 336, 476, 340, 480, 336, 480, 332, 484, 332, 484, 1096, 484, 1096, 480, 336, 480, 1100, 480, 336, 480, 336, 480, 336, 452, 364, 480, 1100, 476, 1104, 480, 336, 480, 336, 476, 340, 476, 336, 480, 336, 484, 332, 480, 336, 456, 360, 480, 336, 480, 336, 480, 336, 480, 336, 480, 336, 480, 336, 480, 336, 480, 336, 480, 336, 480, 336, 480, 336, 480, 336, 452, 364, 480, 336, 476, 340, 480, 332, 484, 336, 476, 336, 480, 336, 480, 336, 480, 336, 480, 336, 480, 336, 452, 364, 480, 336, 476, 1104, 452, 364, 452, 364, 452, 364, 452, 1124, 456, 360, 452, 1128, 452, 1128, 452, 1124, 456, 360, 456, 364, 452, 1124, 452, 1128, 452};
      IrSender.sendRaw(rawData, sizeof(rawData) / sizeof(rawData[0]), NEC_KHZ); // Note the approach used to automatically calculate the size of the array.
  
      Serial.println(F("Send NEC 16 bit address=0xFB04 and command 0x08 with exact timing (16 bit array format)"));
      Serial.flush();
      delay(1000);
        
      Serial.println("- MQTT Sub Conn: (P0) Desligar Ar-condicionado Received");
      Serial.println("---");


      #endif
    }

    else if (msg.equals("A1"))
    {
      #if !(defined(__AVR_ATtiny25__) || defined(__AVR_ATtiny45__) || defined(__AVR_ATtiny85__))
  
      const uint16_t rawData[] = {3112, 1572, 456, 1124, 508, 1072, 504, 312, 456, 360, 504, 312, 504, 1076, 504, 312, 452, 364, 452, 1128, 504, 1072, 508, 312, 452, 1124, 508, 308, 456, 360, 508, 1072, 508, 1072, 456, 360, 504, 1076, 456, 1124, 504, 312, 452, 364, 452, 1128, 452, 364, 504, 312, 504, 312, 452, 1124, 456, 360, 456, 364, 452, 364, 452, 360, 456, 360, 508, 308, 508, 308, 456, 360, 508, 308, 456, 360, 452, 364, 456, 360, 508, 308, 452, 364, 456, 360, 504, 312, 504, 312, 504, 312, 452, 364, 452, 364, 452, 1124, 508, 312, 504, 312, 452, 364, 504, 312, 452, 360, 508, 308, 508, 308, 508, 308, 508, 308, 456, 360, 456, 360, 508, 308, 456, 360, 456, 360, 456, 364, 452, 360, 504, 312, 452, 364, 452, 364, 504, 312, 504, 312, 508, 308, 452, 364, 504, 312, 504, 312, 452, 364, 452, 364, 504, 312, 452, 360, 508, 308, 508, 308, 456, 360, 508, 308, 508, 308, 508, 308, 456, 360, 456, 360, 504, 312, 508, 308, 508, 308, 456, 360, 452, 364, 504, 312, 452, 364, 504, 312, 456, 360, 452, 364, 452, 364, 504, 312, 504, 312, 504, 312, 452, 360, 456, 364, 504, 308, 456, 360, 456, 360, 508, 308, 456, 1124, 456, 360, 504, 1076, 456, 360, 456, 360, 456, 1124, 452, 1128, 504, 312, 504, 3756, 3060, 1624, 460, 1120, 456, 1124, 508, 308, 456, 336, 480, 360, 456, 1124, 456, 360, 504, 312, 456, 1124, 456, 1124, 452, 364, 452, 1128, 504, 312, 452, 364, 452, 1128, 452, 1124, 456, 364, 452, 1124, 456, 1124, 456, 360, 456, 360, 456, 1124, 456, 360, 504, 312, 452, 1128, 504, 312, 504, 312, 452, 364, 452, 364, 452, 364, 504, 312, 452, 364, 452, 364, 452, 360, 456, 364, 452, 360, 508, 308, 456, 360, 456, 360, 456, 360, 456, 360, 456, 360, 452, 1128, 452, 364, 456, 360, 456, 1124, 456, 360, 452, 364, 452, 1128, 452, 1128, 452, 364, 452, 364, 452, 364, 460, 352, 456, 360, 456, 360, 456, 1124, 508, 1072, 456, 360, 452, 1128, 456, 360, 452, 364, 456, 360, 452, 364, 452, 1128, 452, 1128, 452, 360, 456, 364, 452, 360, 456, 360, 508, 308, 456, 360, 456, 360, 456, 360, 456, 360, 456, 360, 456, 360, 456, 360, 456, 360, 456, 360, 456, 360, 456, 360, 456, 360, 456, 360, 456, 360, 452, 340, 476, 364, 504, 312, 452, 364, 452, 364, 456, 360, 452, 364, 452, 364, 452, 360, 456, 360, 456, 364, 452, 360, 456, 360, 456, 360, 456, 1124, 456, 360, 456, 1124, 508, 308, 456, 1124, 452, 364, 456, 1124, 452, 364, 452, 364, 452, 1124, 456, 1124, 456, 1124, 456, 1124, 456};
      IrSender.sendRaw(rawData, sizeof(rawData) / sizeof(rawData[0]), NEC_KHZ); // Note the approach used to automatically calculate the size of the array.
  
      Serial.println(F("Send NEC 16 bit address=0xFB04 and command 0x08 with exact timing (16 bit array format)"));
      Serial.flush();
      delay(1000);
      
        
      Serial.println("- MQTT Sub Conn: (A1) Aumentar Temperatura Received");
      Serial.println("---");


      #endif  
    } 
    
    else if (msg.equals("D1"))
    {
      #if !(defined(__AVR_ATtiny25__) || defined(__AVR_ATtiny45__) || defined(__AVR_ATtiny85__))
  
      const uint16_t rawData[] = {3060, 1624, 456, 1124, 452, 1128, 452, 364, 452, 364, 452, 364, 452, 1128, 480, 332, 484, 336, 452, 1124, 456, 1124, 456, 360, 456, 1124, 456, 360, 452, 364, 456, 1124, 452, 1128, 452, 364, 452, 1128, 452, 1124, 456, 360, 456, 364, 452, 1124, 456, 360, 456, 360, 480, 336, 456, 1124, 480, 336, 452, 364, 452, 364, 452, 364, 452, 364, 452, 364, 452, 364, 452, 364, 452, 364, 452, 360, 456, 364, 452, 360, 484, 332, 456, 360, 456, 360, 456, 360, 456, 360, 456, 360, 456, 360, 456, 360, 456, 1124, 452, 364, 452, 364, 480, 336, 452, 364, 452, 364, 452, 360, 456, 364, 452, 360, 456, 364, 452, 360, 456, 364, 452, 360, 456, 360, 456, 360, 456, 360, 456, 360, 452, 364, 480, 336, 452, 364, 452, 364, 452, 364, 452, 364, 452, 364, 452, 364, 452, 364, 452, 360, 456, 360, 484, 332, 456, 360, 456, 360, 456, 360, 456, 360, 456, 360, 452, 364, 452, 364, 452, 364, 452, 364, 452, 364, 452, 364, 452, 364, 452, 360, 456, 360, 456, 360, 456, 360, 456, 360, 456, 360, 456, 360, 456, 360, 456, 360, 456, 360, 456, 360, 456, 360, 456, 360, 456, 360, 456, 360, 456, 360, 452, 364, 452, 1128, 452, 364, 452, 1128, 452, 360, 456, 360, 484, 1096, 456, 1124, 456, 360, 456, 4628, 3112, 1572, 456, 1124, 452, 1128, 456, 360, 452, 364, 504, 312, 456, 1124, 504, 312, 452, 364, 452, 1128, 452, 1128, 452, 360, 456, 1128, 500, 312, 456, 364, 452, 1124, 456, 1124, 452, 364, 452, 1128, 504, 1076, 504, 312, 452, 364, 456, 1124, 452, 364, 452, 364, 452, 1124, 456, 360, 508, 308, 456, 360, 504, 312, 504, 312, 508, 308, 504, 312, 452, 364, 504, 312, 456, 360, 504, 312, 456, 360, 504, 312, 504, 312, 452, 364, 452, 364, 452, 364, 452, 1128, 504, 308, 508, 308, 456, 1124, 456, 360, 504, 312, 456, 1124, 504, 1076, 452, 364, 452, 364, 452, 364, 456, 360, 452, 368, 448, 364, 452, 1124, 508, 1076, 452, 360, 508, 1072, 456, 360, 504, 312, 456, 360, 508, 308, 456, 1124, 456, 1124, 452, 364, 452, 364, 504, 312, 452, 364, 452, 364, 452, 364, 452, 364, 452, 364, 452, 360, 456, 364, 504, 308, 508, 312, 452, 360, 504, 312, 456, 360, 456, 360, 456, 360, 456, 360, 456, 360, 456, 360, 456, 360, 452, 364, 456, 360, 452, 364, 452, 364, 504, 312, 504, 312, 452, 364, 452, 364, 452, 360, 456, 364, 452, 364, 452, 360, 456, 1124, 508, 308, 456, 360, 456, 360, 504, 1076, 452, 364, 504, 1076, 456, 360, 452, 364, 452, 1128, 452, 360, 456, 1124, 456, 1124, 456};
      IrSender.sendRaw(rawData, sizeof(rawData) / sizeof(rawData[0]), NEC_KHZ);
  
      Serial.println(F("Send NEC 16 bit address=0xFB04 and command 0x08 with exact timing (16 bit array format)"));
      Serial.flush();
      delay(1000);
      
      
      Serial.println("- MQTT Sub Conn: (D1) Diminuir Temperatura Received");
      Serial.println("---");

      #endif
    }
}

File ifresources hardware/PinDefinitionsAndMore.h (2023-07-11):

//ISSO É APENAS O ARQUIVO QUE DEFINE A PORTA QUE O SENSOR INFRAVERMELHO TÁ SENDO UTILIZADO.
//ESSE ARQUIVO FOI RETIRADO DA BIBLIOTECA "IRremote" NO EXEMPLO "SendRawDemo".
/*
 *  PinDefinitionsAndMore.h
 *
 *  Contains pin definitions for IRremote examples for various platforms
 *  as well as definitions for feedback LED and tone() and includes
 *
 *  Copyright (C) 2021-2022  Armin Joachimsmeyer
 *  armin.joachimsmeyer@gmail.com
 *
 *  This file is part of IRremote https://github.com/Arduino-IRremote/Arduino-IRremote.
 *
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
 */

/*
 * Pin mapping table for different platforms
 *
 * Platform     IR input    IR output   Tone      Core/Pin schema
 * --------------------------------------------------------------
 * DEFAULT/AVR  2           3           4         Arduino
 * ATtinyX5     0|PB0       4|PB4       3|PB3     ATTinyCore
 * ATtiny167    3|PA3       2|PA2       7|PA7     ATTinyCore
 * ATtiny167    9|PA3       8|PA2       5|PA7     Digispark pro
 * ATtiny3217  18|PA1      19|PA2      20|PA3     MegaTinyCore
 * ATtiny1604   2           3|PA5       %
 * ATtiny816   14|PA1      16|PA3       1|PA5     MegaTinyCore
 * ATtiny1614   8|PA1      10|PA3       1|PA5     MegaTinyCore
 * SAMD21       3           4           5
 * ESP8266      14|D5       12|D6       %
 * ESP32        15          4           27
 * BluePill     PA6         PA7         PA3
 * APOLLO3      11          12          5
 * RP2040       3|GPIO15    4|GPIO16    5|GPIO17
 */
//#define _IR_MEASURE_TIMING // For debugging purposes.

#if defined(__AVR__)
#if defined(__AVR_ATtiny25__) || defined(__AVR_ATtiny45__) || defined(__AVR_ATtiny85__) // Digispark board
#include "ATtinySerialOut.hpp" // TX is at pin 2 - Available as Arduino library "ATtinySerialOut". Saves 700 bytes program memory and 70 bytes RAM for ATtinyCore
#define IR_RECEIVE_PIN  0
#define IR_SEND_PIN     4 // Pin 2 is serial output with ATtinySerialOut. Pin 1 is internal LED and Pin3 is USB+ with pullup on Digispark board.
#define TONE_PIN        3
#define _IR_TIMING_TEST_PIN 3

#  elif defined(__AVR_ATtiny87__) || defined(__AVR_ATtiny167__) // Digispark pro board
#include "ATtinySerialOut.hpp" // Available as Arduino library "ATtinySerialOut"
// For ATtiny167 Pins PB6 and PA3 are usable as interrupt source.
#  if defined(ARDUINO_AVR_DIGISPARKPRO)
#define IR_RECEIVE_PIN   9 // PA3 - on Digispark board labeled as pin 9
//#define IR_RECEIVE_PIN  14 // PB6 / INT0 is connected to USB+ on DigisparkPro boards
#define IR_SEND_PIN      8 // PA2 - on Digispark board labeled as pin 8
#define TONE_PIN         5 // PA7 - on Digispark board labeled as pin 5
#define _IR_TIMING_TEST_PIN 10 // PA4
#  else
#define IR_RECEIVE_PIN  3 // PA3 - on Digispark board labeled as pin 9
#define IR_SEND_PIN     2 // PA2 - on Digispark board labeled as pin 8
#define TONE_PIN        7 // PA7 - on Digispark board labeled as pin 5
#  endif

#  elif defined(__AVR_ATtiny88__) // MH-ET Tiny88 board
#include "ATtinySerialOut.hpp" // Available as Arduino library "ATtinySerialOut". Saves 128 bytes program memory
// Pin 6 is TX pin 7 is RX
#define IR_RECEIVE_PIN   3 // INT1
#define IR_SEND_PIN      4
#define TONE_PIN         9
#define _IR_TIMING_TEST_PIN 8

#  elif defined(__AVR_ATtiny1616__)  || defined(__AVR_ATtiny3216__) || defined(__AVR_ATtiny3217__) // Tiny Core Dev board
#define IR_RECEIVE_PIN  18
#define IR_SEND_PIN     19
#define TONE_PIN        20
#define APPLICATION_PIN  0 // PA4
#undef LED_BUILTIN         // No LED available on the TinyCore 32 board, take the one on the programming board which is connected to the DAC output
#define LED_BUILTIN      2 // PA6

#  elif defined(__AVR_ATtiny816__) // Tiny Core Micro
#define IR_RECEIVE_PIN  14 // PA1
#define IR_SEND_PIN     16 // PA3
#define TONE_PIN         1 // PA5
#define APPLICATION_PIN  0 // PA4
#undef LED_BUILTIN         // No LED available, take the one which is connected to the DAC output
#define LED_BUILTIN      4 // PB5

#  elif defined(__AVR_ATtiny1614__)
#define IR_RECEIVE_PIN   8 // PA1
#define IR_SEND_PIN     10 // PA3
#define TONE_PIN         1 // PA5
#define APPLICATION_PIN  0 // PA4

#  elif defined(__AVR_ATtiny1604__)
#define IR_RECEIVE_PIN   2 // To be compatible with interrupt example, pin 2 is chosen here.
#define IR_SEND_PIN      3
#define APPLICATION_PIN  5

#define tone(...) void()      // Define as void, since TCB0_INT_vect is also used by tone()
#define noTone(a) void()
#define TONE_PIN        42 // Dummy for examples using it
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

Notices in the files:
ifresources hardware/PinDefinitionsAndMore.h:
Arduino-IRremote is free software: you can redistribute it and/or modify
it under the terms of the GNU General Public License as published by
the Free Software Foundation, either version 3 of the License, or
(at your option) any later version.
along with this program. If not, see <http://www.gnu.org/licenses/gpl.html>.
